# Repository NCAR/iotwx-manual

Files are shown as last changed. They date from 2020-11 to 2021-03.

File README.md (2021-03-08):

# IoTwx Manual

The process for building your station follows 5 major steps:

1. [PLAN](/plan): in this step you will plan out the design of your
   station. The components, sensors, physical design, etc. will all be
   taken into account during this phase.
2. [BUILD](./build): in this step you will begin the building process.
   You will gather your frame parts, wires, and PVC and build the frame
   so it is ready for your sensors and microcontrollers.
3. [FLASH](./flash): in this step you will build the source files and
   flash them onto your device. Should you want to flash the binaries
   directly, there are instructions to do so.
4. [DATA](./data): in this step you will set up how your data will be 
   transmitted, stored and otherwise displayed, archived or distrubuted.
4. [TEST](./test): making sure each node works as expected will insure
   the best experience for your deployment.
5. [DEPLOY](./deploy): siting and deploying are the final step in
   getting you on your way to your first 3d-printed automated weather
   station.
   
   As this is a community driven project, we value your feedback and contributions to improve the weather station. 
   To contribute updates and changes, you may fork and modify this repo for merging or, more simply, submit issues or comments via [New Issues button]( https://github.com/NCAR/iotwx-manual/issues)

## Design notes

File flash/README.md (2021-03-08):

# Flashing Microcontrollers

Each station node is build atop a microcontroller, where each
microcontroller is connected to one or more sensors either directly or
by [Grove hubs](https://www.seeedstudio.com/Grove-I2C-Hub.html). 

IotWx is designed to be used with the [m5Stack Atom Lite](https://m5stack.com/collections/m5-core/products/atom-lite-esp32-development-kit)
ESP32-Pico based microcontroller.  

There are two nodes that the core Arduino code has been developed for.
Before compiling the microcode onto the Arduino, you will also need to
install the core IoTwx shared library which controls many of the
communications and initialization functions of each node.

This core library can found at the following repository. It should be
installed in your `Arduiono/libraries` directory and once installed, you
may use it by the `#include "IoTwx.h"` directive.

* [https://github.com/NCAR/esp32-atomlite-arduino-iotwx](https://github.com/NCAR/esp32-atomlite-arduino-iotwx)

Please see the
[parts list](https://drive.google.com/file/d/1lAb784yfsxWOiH-yVCXQ3Ii0yEgUmtUQ/view?usp=sharing)
for the microcontroller, sensors and cables required or recommended to
build and connect a base system.

## Preparing Your System

You will need to install the [latest version of Arduino](https://www.arduino.cc/en/Main/Software) on your system to begin.

There are a few other steps you will need to complete:

* install the required ESP32 Pico / M5 Stack Atom lite boards; a comprehensive instruction set is [here](https://docs.m5stack.com/#/en/arduino/arduino_development)
* install the [arduino-esp32fs-plugin](https://github.com/me-no-dev/arduino-esp32fs-plugin) that will allow SPIFFS file uploads to ESP32 boards
* install the following libraries through the Arduino IDE:
  * MQTT library from 256dpi [https://github.com/256dpi/arduino-mqtt](https://github.com/256dpi/arduino-mqtt)
  * SeeedStudio VEML6070 library [https://github.com/Seeed-Studio/Seeed_VEML6070](https://github.com/Seeed-Studio/Seeed_VEML6070)
  * SeeedStudio BME280 library [https://github.com/Seeed-Studio/Grove_BME280](https://github.com/Seeed-Studio/Grove_BME280)
  * SeeedStudio BME680 library [https://github.com/Seeed-Studio/Seeed_BME680](https://github.com/Seeed-Studio/Seeed_BME680)
  * ArduinoJson library [https://github.com/bblanchon/ArduinoJson](https://github.com/bblanchon/ArduinoJson)
  * FastLED library [https://github.com/FastLED/FastLED](https://github.com/FastLED/FastLED)
  * NTPClient library [https://github.com/arduino-libraries/NTPClient](https://github.com/arduino-libraries/NTPClient)

## Editing and Flashing Configuration Files

Each node must contain a configuration file in order to operate.  The file contains information about WiFi connections, MQTT connections and some information about the node.

We are using the [ESP32 SPIFFS filesystem](https://docs.espressif.com/projects/esp-idf/en/latest/esp32/api-reference/storage/spiffs.html) to store the configuration.  In the repositories of each node, you will find a `data` folder which contains a `config.json` file.

### `config.json` details

The typical config file  follows:

```json
{    
    "iotwx_local_config":"1",
    "iotwx_id":"m5atom/esp32/aaffbbcc",
    "iotwx_mq_ip":"",
    "iotwx_mq_port":"1883",
    "iotwx_publish_interval":"1",
    "iotwx_reset_interval":"360",
    "iotwx_sensor":"grove/i2c",
    "iotwx_timezone":"21600",
    "iotwx_wifi_pwd":"",
    "iotwx_wifi_ssid":"",
    "iotwx_topic":"measurements/iotwx",
    "iotwx_max_frequency":"240"
}
```

* `iotwx_local_config` should always be set to `1`.

* `iotwx_id` should contain a _unique_ identifier for you station as a whole -- that is to say, if you have multiple nodes on the same _physical station_, they would share the same `iotwx_id`.  This identifier is also used in the data portal.

* `iotwx_mq_ip` contains the ip address (e.g. `''172.88.0.13"`) of the MQTT broker you will be using.  At the moment only one such broker is allowed. You may use the FQDN (`"mymqttsite.wx"`) but the IP address uses less power by reducing the time WiFi is on to do DNS lookups.

* `iotwx_mq_port` contains the port number of the broker, which is typically `"1883"`.

* `iotwx_publish_interval` contains the interval you wish your station to transmit in _minutes_.  Note this is relevant primarily for the Atmos node which continuously transmits at the specified interval. Hydro and Aero nodes only transmit when there is data to transmit.

* `iotwx_reset_interval` is the number of minutes between system resets.  The nodes are designed to reset every 6 hours or twice daily.  Reset is instantaneous and the system is restored to full functionality in 90 seconds after the Bluetooth acquisition phase.

* `iotwx_sensor` is the sensor string for the node and may vary based on the node.  Typically do not change this value from what is contained in the default for your node.

* `iotwx_timezone` is the GMT offset in seconds of the station timezone.

* `iotwx_wifi_pwd` and `iotwx_wifi_ssid` are the corresponding wifi password and ssid of the network your node will connect to.  Note, it is not necessary (but would be unusual) for all nodes to connect to the same WiFi network.

* `iotwx_topic` contains the MQTT topic your node will publish to.  It is not necessary for all nodes to publish to the same topic, but if you are using the CHORDS MQTT Orchestrator ([GitHub - NCAR/chords-mqtt-orchestrator](https://github.com/NCAR/chords-mqtt-orchestrator)), then you will need to adjust it accordingly to route your messages where they belong.  The current default is `"measurements/iotwx"`

* `iotwx_max_frequency` is the CPU frequency (in Mhz) you wish your node to run  on.  The m5Stack Atom Lite can be run at frequencies up to 240, but has only been tested down 40 Mhz.  The AeroNode must be set to above `"160"` and runs best at `"240"`.  The Hydro node has been successfully configured at `"40"`  and the Atmos node's best performance is at `"80"`.  Varying the value has power-saving benefits, where we have seen 20-50% reduction in power consumption of a node.

## Atmos Node

The Atmos node is comprised of two sensors and two 3d-printed housing
units. The first sensor houses the atmospheric conditions for air
temperature, humidity and barometric pressure. It can be fitted with the
[Seeedstudio BME280 Grove](https://www.seeedstudio.com/Grove-BME280-Environmental-Sensor-Temperature-Humidity-Barometer.html)
environmental sensor, or if you would like to obtain aggregate VOC
measurements, you can fit the housing with the
[BME680 Grove](https://www.seeedstudio.com/Grove-Temperature-Humidity-Pressure-and-Gas-Sensor-for-Arduino-BME680.html)
sensor. The code is designed to work with both sensors (but not
simultaneously). These parts can be found in the
[parts list](https://drive.google.com/file/d/1lAb784yfsxWOiH-yVCXQ3Ii0yEgUmtUQ/view?usp=sharing).

### Radiation Shield

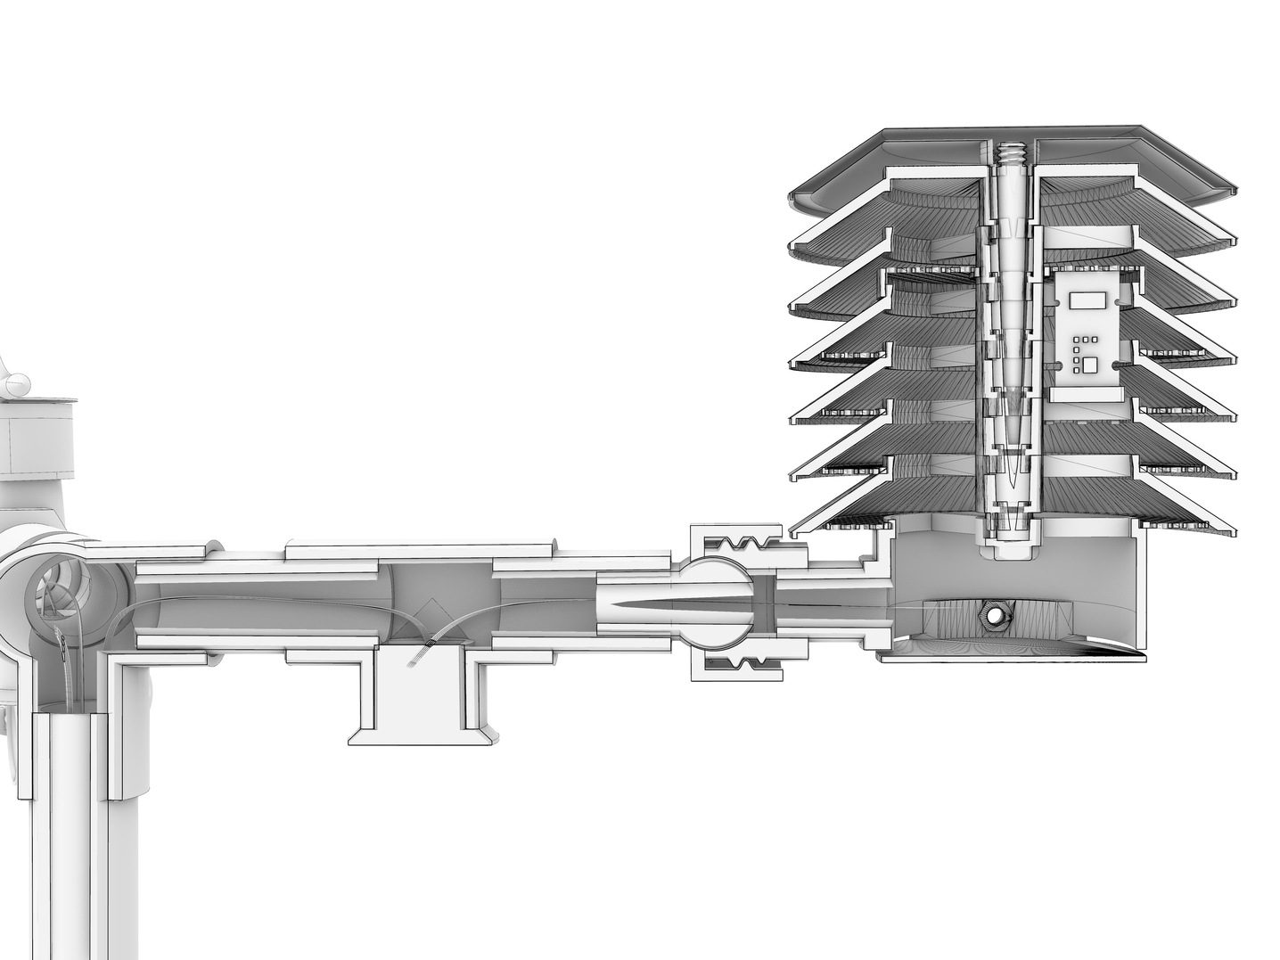
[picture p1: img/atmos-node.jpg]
atmos node


The radiation shield sensor captures the following measurements:
temperature, humidity, barometric pressure, and optionally VOC (if using
the BME680 sensor).

**PRINTING**

* the radiation shield design 3d print files can be found in the
  [`/build/stl/atmos`](https://github.com/NCAR/iotwx-manual/tree/master/build/stl/atmos) page. If you need to
  print, you will need to follow the instructions there to print the
  housing.

**FLASHING**

* the code to flash the node can be found in the
  [esp32-atomlite-arduino-atmos-node repository](https://github.com/NCAR/esp32-atomlite-arduino-atmos-node).
  You will to follow the instructions there to understand the Arduino
  flashing requirements and procedures.

### UV

Because the UV measurement is part of the Atmos node, the code already
includes the capability to capture and transmit measurements. It is
integrated in to the
[esp32-atomlite-arduino-atmos-node repository](https://github.com/NCAR/esp32-atomlite-arduino-atmos-node)
and hence no other changes or files are necessary to flash once that
file has been uploaded to the microcontroller.

## Hydro Node

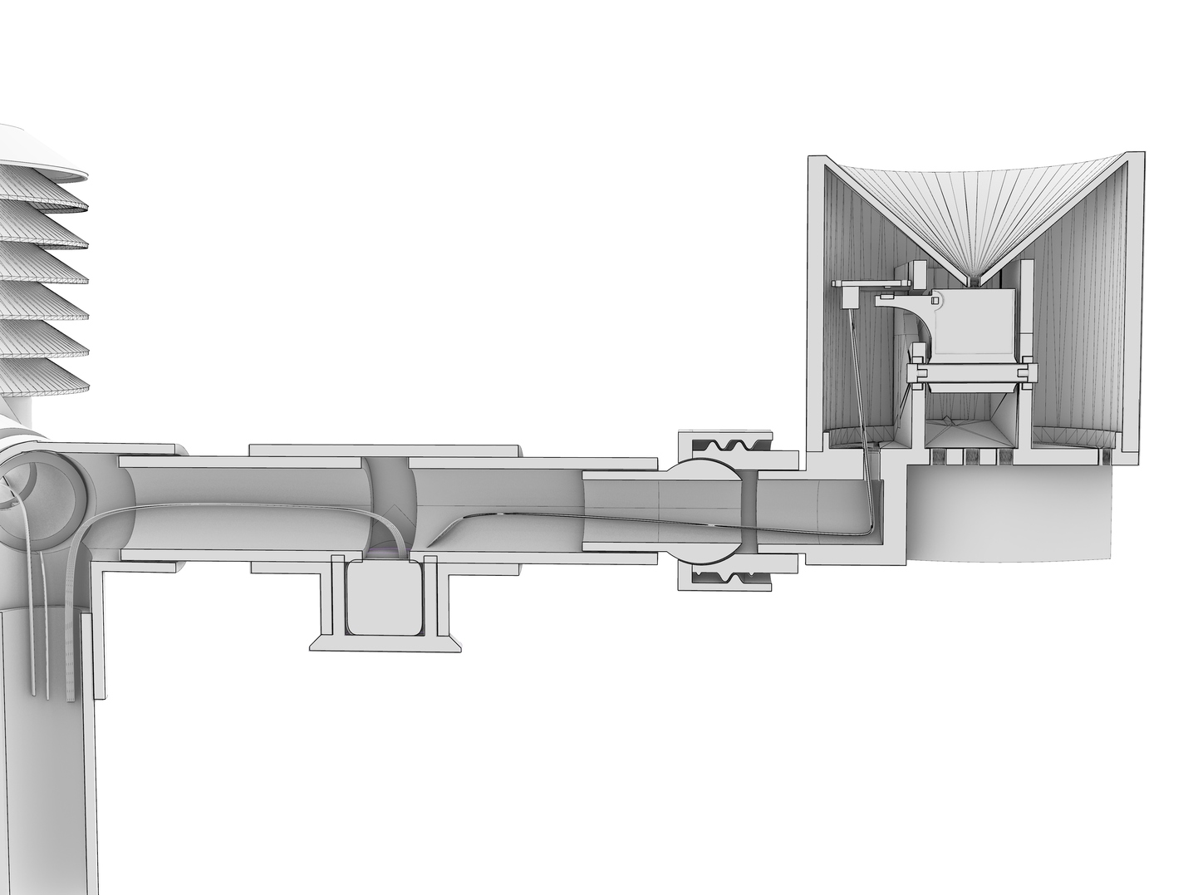
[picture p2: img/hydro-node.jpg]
hydro node


The hydro node is designed to collected and transmit precipitation
measurements.  

**PRINTING** 

* the rain gauge design 3d print files can be found in the
  [`/build/stl/hydro`](https://github.com/NCAR/iotwx-manual/tree/master/build/stl/hydro)
  page. If you need to print, you will need to follow the instructions
  there to print the housing.

**FLASHING**

* the code to flash the node can be found in the
  [esp32-atomlite-arduino-hydro-node repository](https://github.com/NCAR/esp32-atomlite-arduino-hydro-node).
  You will to follow the instructions there to understand the Arduino
  flashing requirements and procedures.

## Aero Node

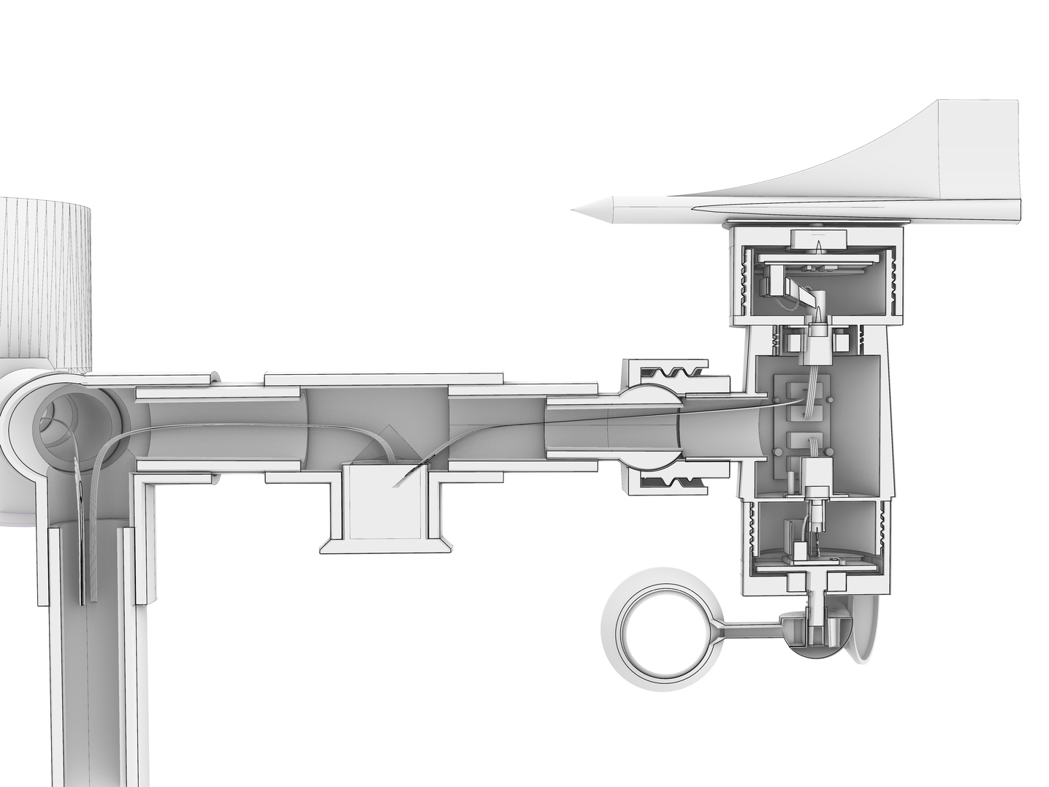
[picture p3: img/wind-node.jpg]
aero node


The aero node is designed to collect wind vane & anemometer wind speed
and direction.

* Instructions for printing and flashing are forthcoming.

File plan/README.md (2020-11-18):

# Planning Your Station Build & Deployment

In general, planning your station is easy. While we recommend you use PVC for the 
main frame of the station, you may use any materials you like as long as they bind to 
the ABS/PLA plastic of the 3D-printed parts.

The base configuration of the station includes three nodes and the power (we'll 
consider the power a node as well moving forward).  You may reduce or expand those 
nodes based on your specific needs, but the base configuration will be assumed in 
this guide.

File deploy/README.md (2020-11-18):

## Picking a good site

   ### Classroom Site Near Wifi
   ### Site Away From Wifi Using USB Modem

## Publishing and Visualizing Station Data

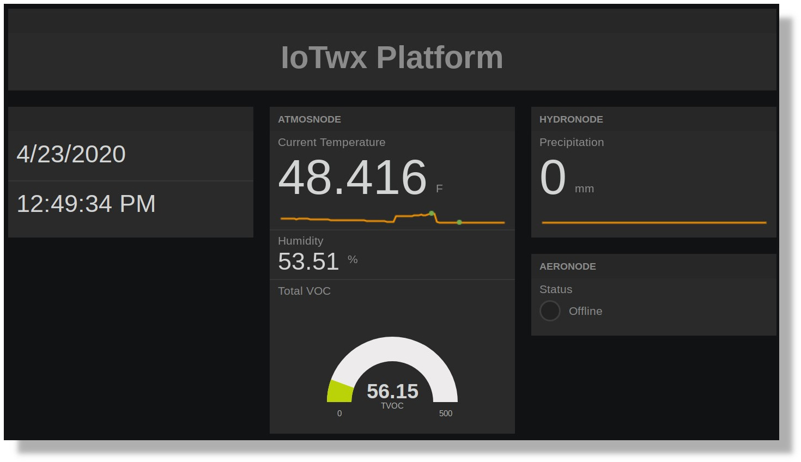
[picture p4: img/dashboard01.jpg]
dashboard


--

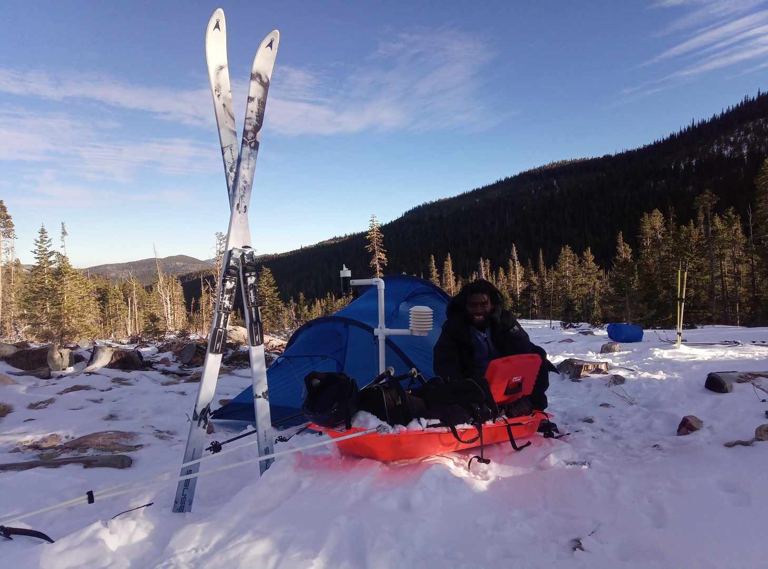
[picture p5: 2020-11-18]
img/deployment1.jpg

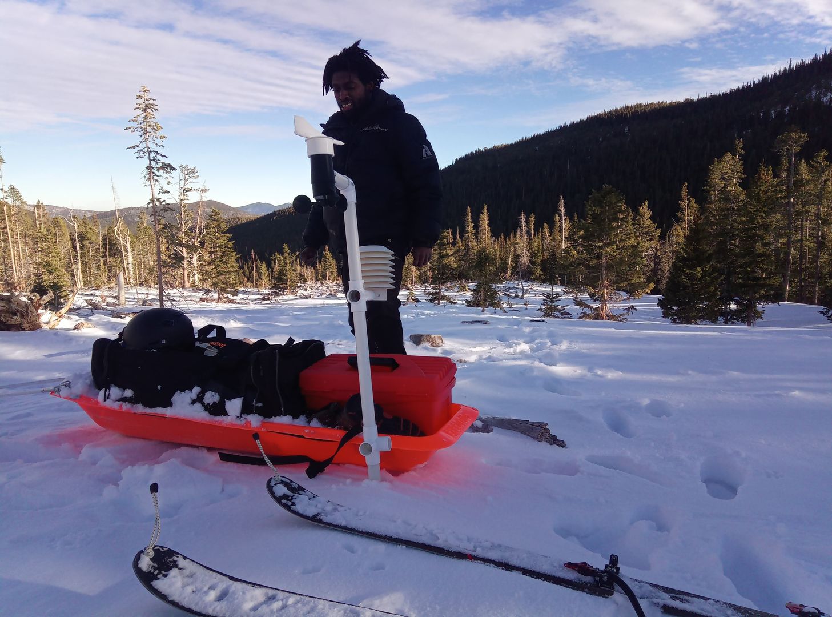
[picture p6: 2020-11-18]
img/mission.jpg

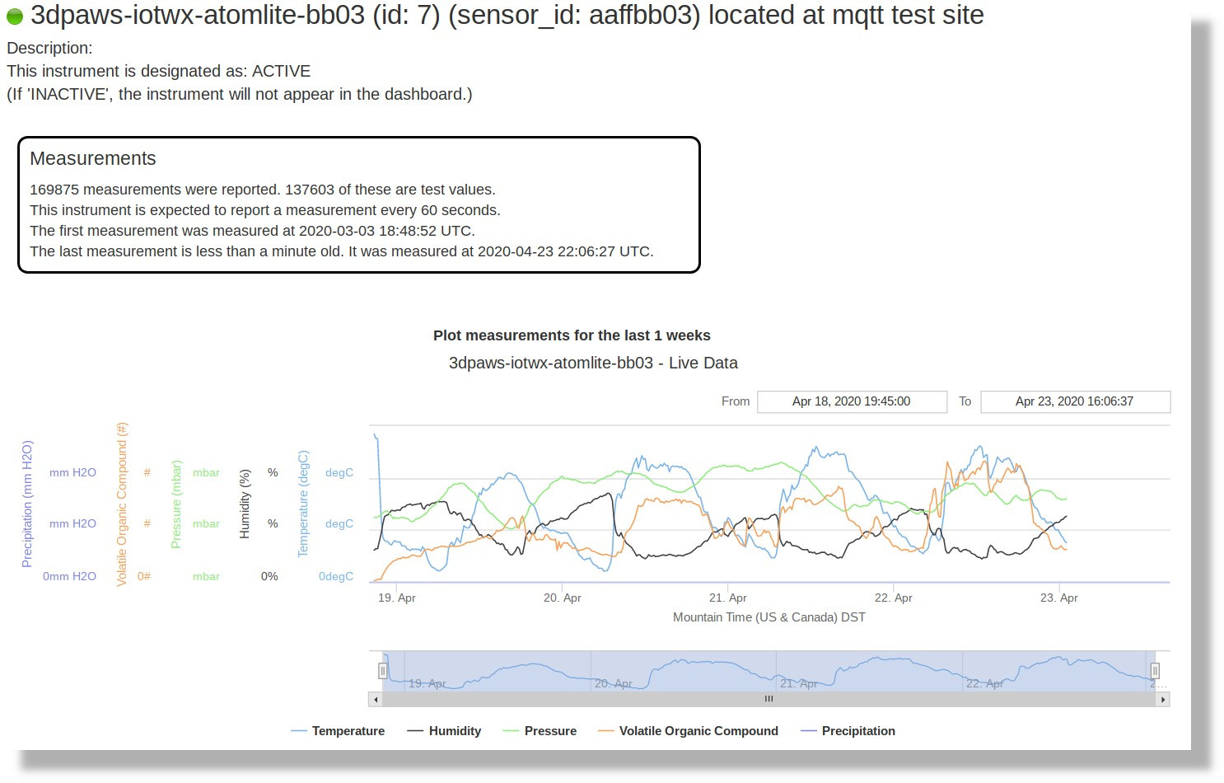
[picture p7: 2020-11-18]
img/chords01.jpg

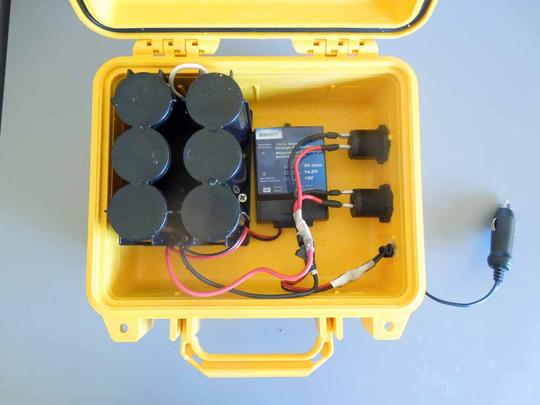
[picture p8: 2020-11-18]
img/powercomm-node.jpg

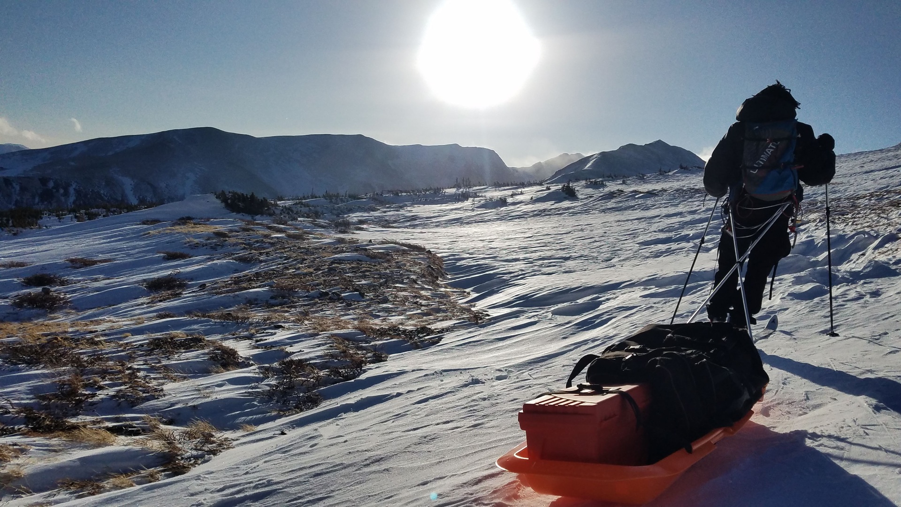
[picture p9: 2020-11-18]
img/deployment2.jpg

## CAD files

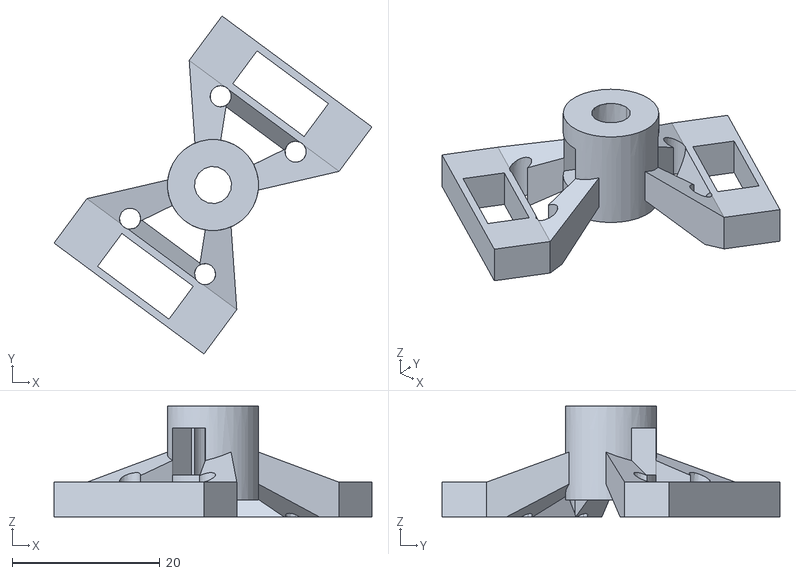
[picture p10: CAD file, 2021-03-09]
build/stl/aero/aero_wnvn_coupler_4.stl
43.1 x 45.8 x 15.0

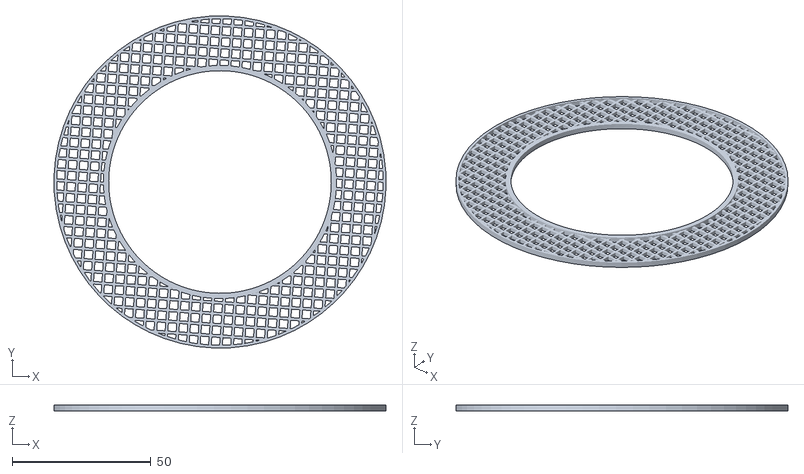
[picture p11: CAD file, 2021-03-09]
build/stl/atmos/rs_screen_ring.stl
119.9 x 119.9 x 2.00

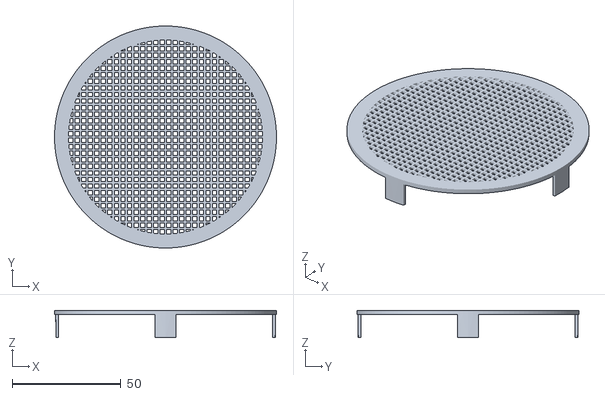
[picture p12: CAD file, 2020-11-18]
build/stl/hydro/hyd_funnel_screen.stl
101.9 x 101.9 x 12.5

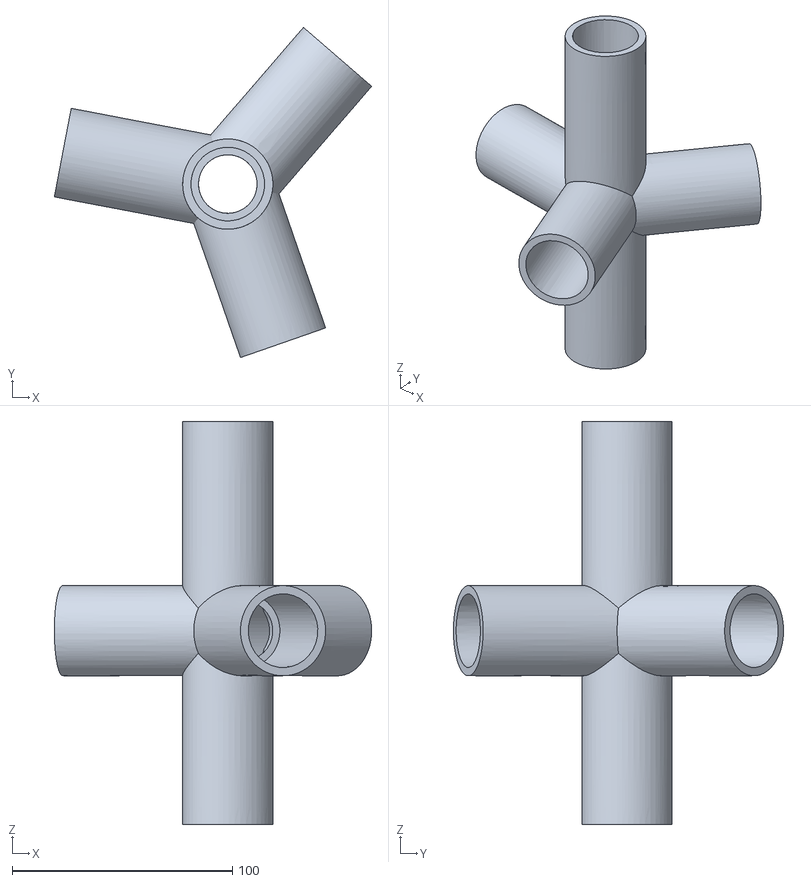
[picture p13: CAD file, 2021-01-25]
build/stl/pvc/pvc_mid_splitter.stl
144.2 x 150.0 x 183.1

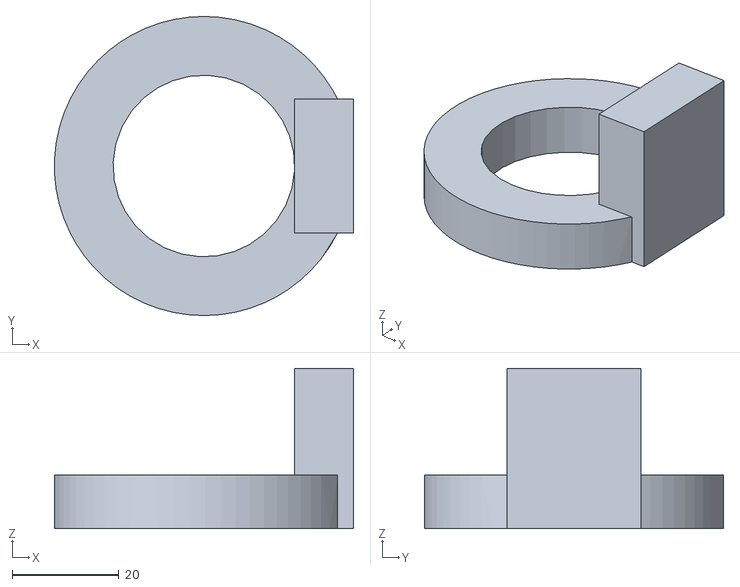
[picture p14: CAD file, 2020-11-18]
build/stl/solar/sol_11mil_clamp.stl
56.0 x 56.0 x 30.0

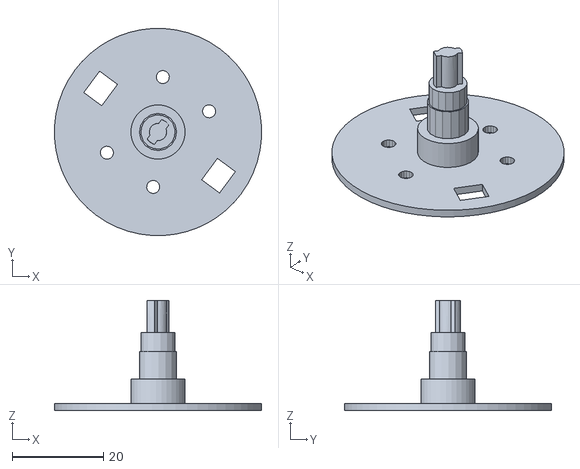
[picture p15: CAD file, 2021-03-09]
build/stl/aero/aero_wnvn_plate_4.stl
45.5 x 45.5 x 24.2

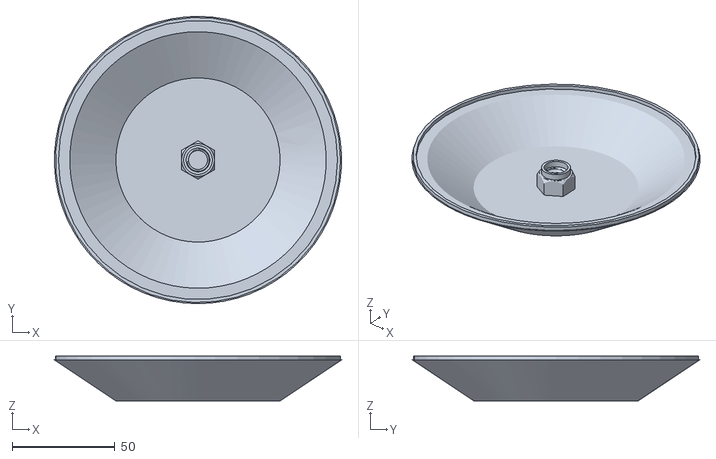
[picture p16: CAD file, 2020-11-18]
build/stl/atmos/rs_top_leaf.stl
139.8 x 139.9 x 21.9

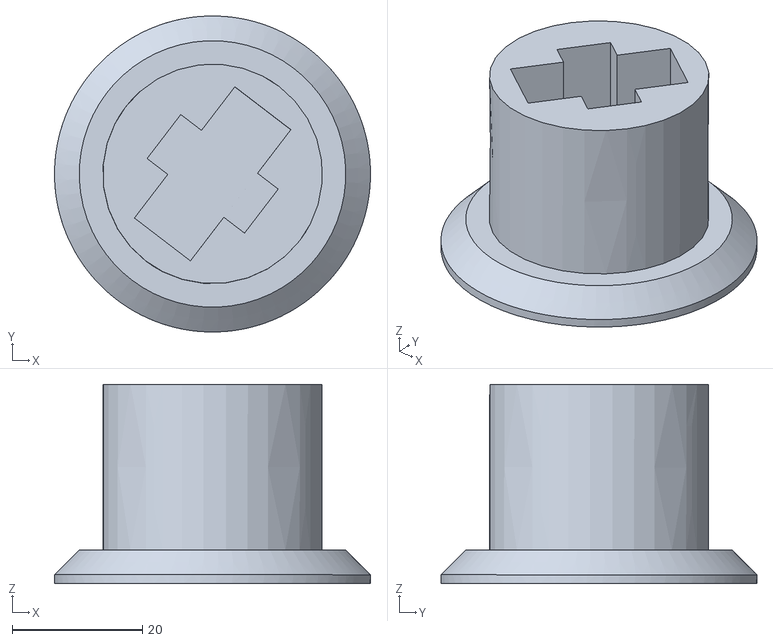
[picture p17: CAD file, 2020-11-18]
build/stl/hydro/pvc_micro_holder.stl
48.5 x 48.5 x 30.6

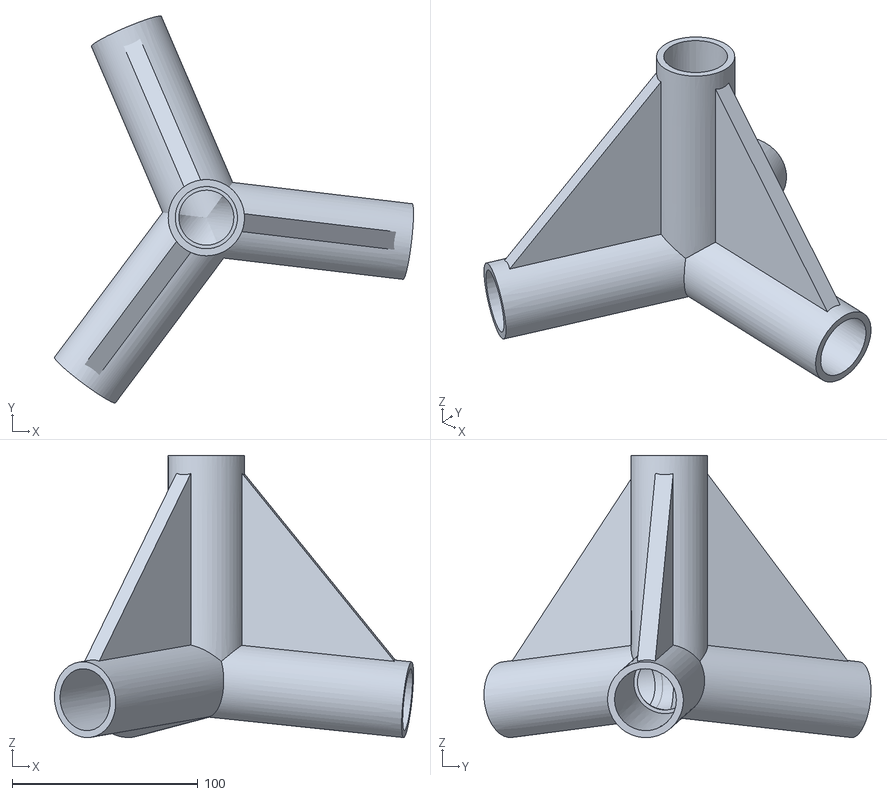
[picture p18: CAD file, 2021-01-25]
build/stl/pvc/pvc_tripod_base_2.stl
193.1 x 208.1 x 151.8

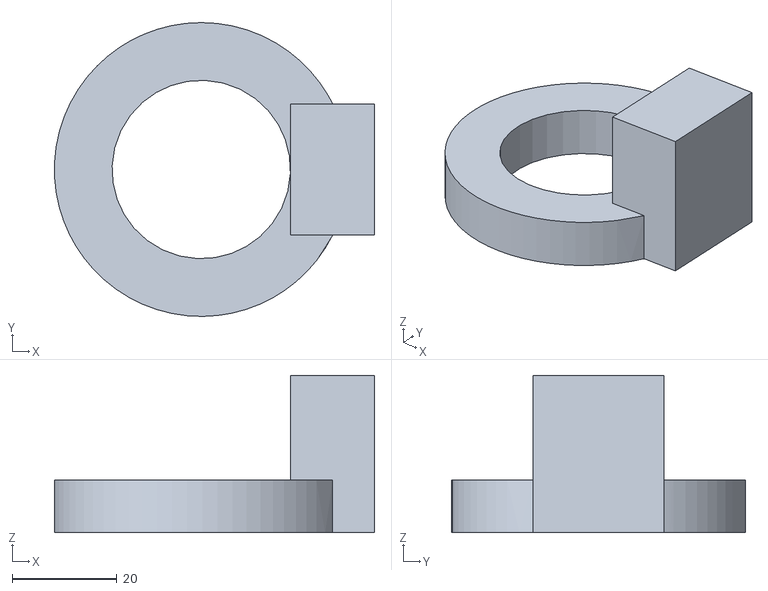
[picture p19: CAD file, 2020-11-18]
build/stl/solar/sol_16mil_clamp.stl
61.0 x 56.0 x 30.0

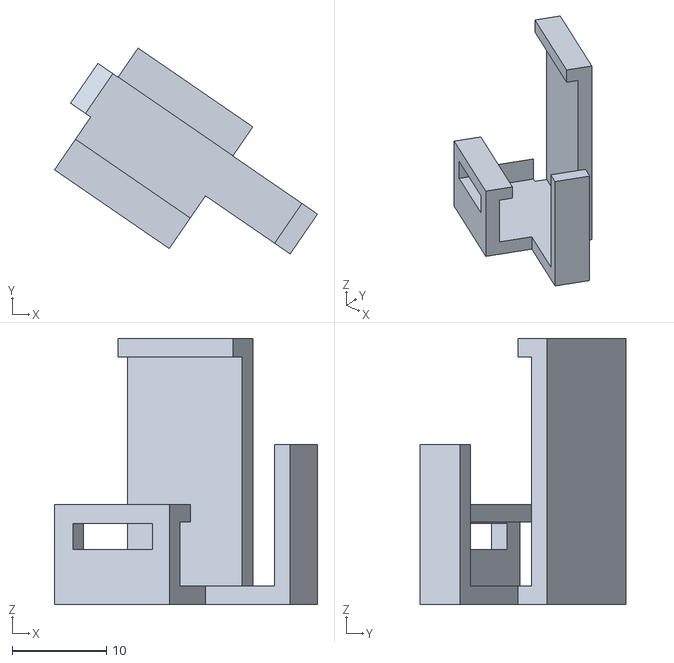
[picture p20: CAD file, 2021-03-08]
build/stl/aero/aero_micro_harness.stl
27.9 x 21.8 x 28.2

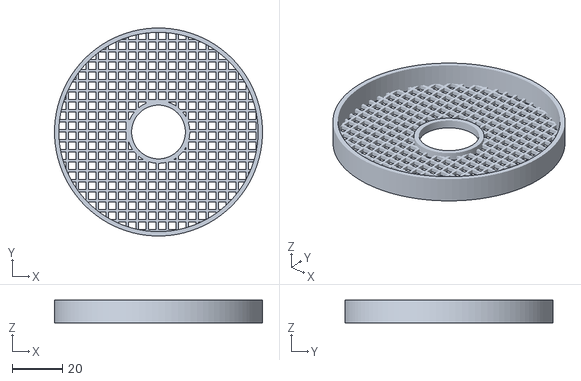
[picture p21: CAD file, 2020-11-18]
build/stl/atmos/rs_center_screen.stl
83.0 x 83.0 x 9.00

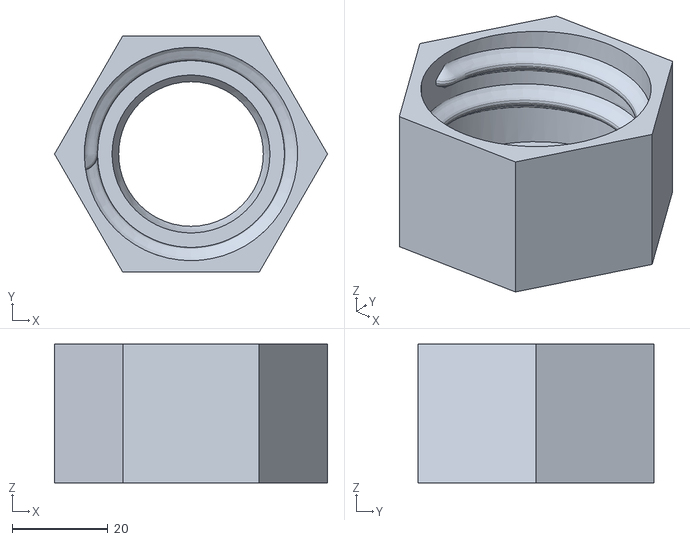
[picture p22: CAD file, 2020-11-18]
build/stl/hydro/swvl_outerlock.stl
56.9 x 49.3 x 29.0

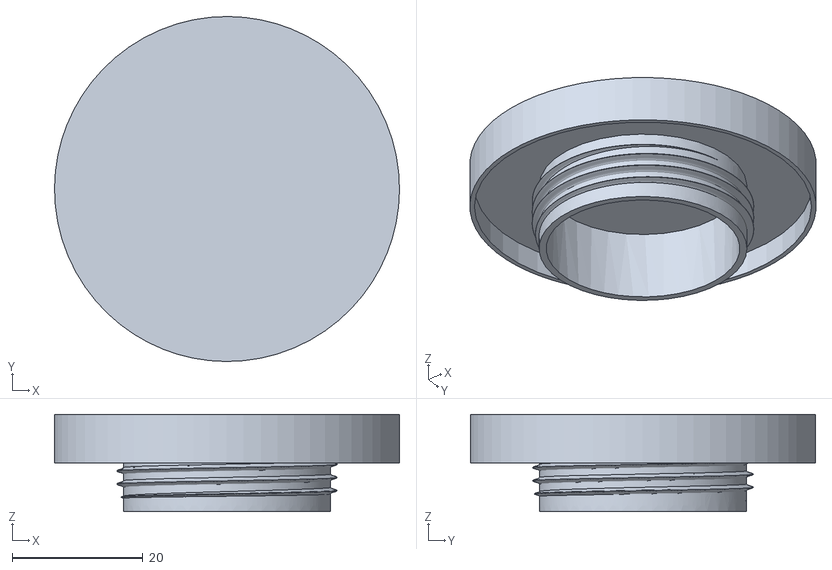
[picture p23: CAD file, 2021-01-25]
build/stl/aero/aero_wnvn_cap_2.stl
52.8 x 52.8 x 14.9

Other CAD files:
build/stl/pvc/pvc_tri_splitter_2.stl
build/stl/atmos/uv_cap.stl
build/stl/hydro/hyd_funnel.stl
build/stl/pvc/pvc_tripod_base_3.stl
build/stl/aero/aero_wnvn_clips_3.stl
build/stl/aero/aero_wnvn_coupler_3.stl
build/stl/aero/aero_wnvn_plate_3.stl
build/stl/atmos/rs_base.stl
build/stl/atmos/rs_base_plate.stl
build/stl/atmos/rs_clip.stl
build/stl/atmos/rs_fasteners.stl
build/stl/atmos/rs_shaft.stl
build/stl/atmos/rs_single_leaf.stl
build/stl/atmos/swvl_balljoint_bar.stl
build/stl/atmos/swvl_innerlock.stl
build/stl/atmos/uv_tube.stl
build/stl/hydro/hyd_fulcrum.stl
build/stl/hydro/hyd_rain_guage.stl
build/stl/hydro/swvl_balljoint_bar.stl
build/stl/hydro/swvl_innerlock.stl
build/stl/pvc/pvc_balljoint_bar.stl
build/stl/pvc/pvc_en_cap.stl
build/stl/pvc/pvc_en_tube.stl
build/stl/pvc/pvc_innerlock.stl
build/stl/pvc/pvc_stake.stl
build/stl/pvc/pvc_tjoint.stl
build/stl/pvc/pvc_tri_splitter.stl
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

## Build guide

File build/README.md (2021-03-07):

# Building Your Station

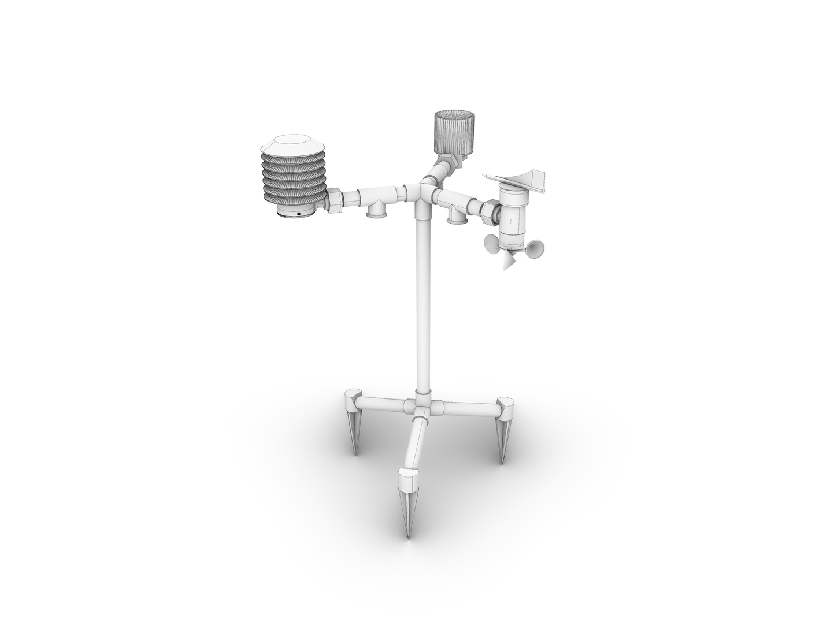
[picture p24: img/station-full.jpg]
atmos node


**PARTS LIST**

Before getting started, you should consult the complete list of parts
and hardware that can be found at:

* See the
  [Google spreadsheet](https://drive.google.com/file/d/1lAb784yfsxWOiH-yVCXQ3Ii0yEgUmtUQ/view?usp=sharing)
  for the full, up-to-date list of _non-printed_ parts for building a
  complete station. The vast majority of parts can be found on Amazon,
  through online electronics distributors and through your local
  hardware store.

**Note:** the base case build has quantities preset to 1 item. Also,
**alternative power options** are also listed in this document for users
interested in further customizing their station to specific power needs.

If you only wish to do tabletop testing, you will only need to follow
the [flash instructions](https://github.com/NCAR/iotwx-manual/tree/master/flash) for the microcontroller and then proceed to
the [tabletop testing](#skeletontabletop-testing). This will eliminate
the need for making wiring bundles, constructing a PVC frame or printing
the 3d-printed housing.

## 3D-Printing

All parts can be found in the [stl](./stl) folder and in conjection 
with the station assembly instructions.

Reference stations have been produced with PLA+ material, but
ABS and other materials may be used, provided you have 
enough expertise using them.

## Framing

* [PVC Framing Stand Assembly](./NCAR_PVC_Node_Assembly_Doc.pdf) instruction set

## Wiring

All wiring is based on the Grove / PH2.0-4P which is a 4 pin cable capable of carrying digital, analog and I2C signals.  Grove cables come in buckled and unbuckled styles as well as many sizes from 20cm to 2m.  Grove cables can also be connected directly to GPIOs with both male and female jumper cables.

An assortment of cables can be reliably found here: [Search results for: grove cable – Mouser](https://www.mouser.com/Search/Refine?Keyword=grove+cable).

Long cable (1m - 2m) can be found here: [Unbuckled Grove Cable 1m/2m/50cm/20cm/10cm | m5stack-store](https://m5stack-store.myshopify.com/collections/m5-accessory/products/4pin-buckled-grove-cable)

### Qwicc

There are many Grove sensors provided by SeeedStudio, but another connector standard also exists to open up even more sensors. Deveopled by Sparkfun, [Qwicc](https://www.sparkfun.com/qwiic) is also a 4 pin I2C connector that is capable of being connected to Grove and visa-versa.  If you wish to explore the wide variety of sensors, browse what's possible from [Qwiic Sensors: SparkFun Electronics](https://www.sparkfun.com/categories/399)), [STEMMA/Qwiic Sensors: Adafruit Industries, Unique &amp; fun DIY electronics and kits](https://www.adafruit.com/category/1005), [Qwiic ModulesL Smart Prototyping Zio](https://www.smart-prototyping.com/Zio/zio-modules) and others. 

We have been successful using Adafruit Qwiic digital compass sensors in the AeroNode.

### GPIO Connections

If you want to connect directly to the GPIO (either using the recommended reference microcontroller m5Stack Atom Lite or some other microcontroller), the male and female jumper cables can be used as needed:

* male 4 pin Grove Jumper cable: [110990210 Seeed Studio | Mouser](https://www.mouser.com/ProductDetail/Seeed-Studio/110990210?qs=1%252B9yuXKSi8A2O44lPDM%252BLw%3D%3D)

* female 4 pin Grove Jumper cable: [110990028 Seeed Studio | Mouser](https://www.mouser.com/ProductDetail/Seeed-Studio/110990028?qs=1%252B9yuXKSi8Bgmubyjm2m%2Fw%3D%3D)

## Station Assembly

You can find the various assembly instructions in the provided PDF files:

* [Aero Node Assembly](./NCAR_AERO_Node_Assembly_Doc.pdf) instruction set
* [Hydro Node Assembly](./NCAR_HYDRO_Node_Assembly_Doc.pdf) instruction set
* [Atmos Node Assembly](./NCAR_ATMOS_Node_Assembly_Doc.pdf) instruction set

This is a community driven project, if you would like to contribute proposed changes to the assembly instructions or see other issues please submit it via [New Issues]( https://github.com/NCAR/iotwx-manual/issues)

## Skeleton/Tabletop Testing

The IoTwx system is designed to allow for rapid and flexible testing well _before_ assembly.  In fact, you can set up a system without any frame at all to burn in, test or add new components.

Simply flash the code onto the microcontroller, connect the sensors and you're done.

## Solar Assembly

*coming soon

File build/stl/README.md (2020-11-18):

# STL files for printing

There are directories containing all the STL files necessary to print the 
station.  The following nodes are available for printing.  Please consult
the [parts list](https://drive.google.com/file/d/1lAb784yfsxWOiH-yVCXQ3Ii0yEgUmtUQ/view?usp=sharing) and [flash instructions](https://github.com/NCAR/iotwx-manual/tree/master/flash) for the other parts (electronics, etc.) 
and code that are necessary to construct a fully operational node.

* [atmos node files](./atmos) are available for the radiation shield
* [hydro node files](./hydro) are available for the tipping bucket
* [aero node files](./aero) are available for the wind vane and anemometer 
* [solar assembly files](./solar) are available for the solar panel assembly
* [pvc connectors files](./pvc) are available for the pvc connectors

# Acknowledgements

This design would not have been possible without the enumerable contributions of others.

In particular, the Atmos node is inspired by the work of the [3D-PAWS radiation shield assembly](https://sites.google.com/ucar.edu/3dpaws/instruments/radiation-shield) ((c) UCAR/COMET)
from which modifications were made to accommodate different sensor orientations, to allow
for easier insertion of the leaf screens and changes were made to the shaft for 
improved threading and durability. The Hydro node is remixed and modified from the 
original work of [RobWLake's LTB Weather Station](https://www.thingiverse.com/thing:2849562) 
(CC-BY-NC 4.0) -- changes were made to the sensor holder to accommodate a [Grove hall effect sensor](https://wiki.seeedstudio.com/Grove-Hall_Sensor/) and a debris screen, 
as well as sizing modifications so that it is easier to construct.

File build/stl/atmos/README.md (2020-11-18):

# Print Settings

Unless otherwise noted, **infill default is 50%**.

| Description | File | Quantity | Notes |
|---|---|---|---|
| Base | [rs_base.stl](./rs_base.stl) | 1 | |
| Center Screen | [rs_center_screen.stl](./rs_center_screen.stl) | 1 | |
| Sensor clip holder | [rs_clip.stl](./rs_clip.stl) | 1 | Print more than 1 if you have multiples or need extras. |
| Middle leaf | [rs_mid_leaf.stl](./rs_mid_leaf.stl) | 1 | |
| Screen Ring | [rs_screen_ring.stl](./rs_screen_ring.stl) | 4 | |
| Center shaft | [rs_shaft.stl](./rs_shaft.stl) | 1 | Print at 100% infill |
| Single leaf | [rs_single_leaf.stl](./rs_single_leaf.stl) | 1 | |
| Top leaf | [rs_top_leaf.stl](./rs_top_leaf.stl) | 1 | |
| Base Fasteners | [rs_fasteners.stl](./rs_fasteners.stl) | 2 | Print at 100% infill; print extras as needed. |  | |
| Swivel ball joint connector | [swvl_balljoint_bar.stl](./swvl_balljoint_bar.stl) | 1 | |
| Swivel ball joint inner locl |[swvl_innerlock.stl](./swvl_innerlock.stl) | 1 | |
| Swivel ball joint outer lock | [swvl_outerlock.stl](./swvl_outerlock.stl) | 1 | |
| Microcontroller holder  | [pvc_micro_holder.stl](./pvc_micro_holder.stl) | 1 | |

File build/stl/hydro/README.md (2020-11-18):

# Print Settings

Unless otherwise noted, **infill default is 50%**.

| Description | File | Quantity | Notes |
|---|---|---|---|
| Fulcrum | [hyd_fulcrum.stl](./hyd_fulcrum.stl) | 1 | Print more than 1 if you need extras |
| Funnel Screen | [hyd_funnel_screen.stl](./hyd_funnel_screen.stl) | 1 | |
| Funnel | [hyd_funnel.stl](./hyd_funnel.stl) | 1 |  |
| Rain gauge | [hyd_rain_guage.stl](./hyd_rain_guage.stl) | 1 | |
| Sensor Slot | [hyd_sensor_slot.stl](./hyd_sensor_slot.stl) | 1 |  |
| Swivel ball joint connector | [swvl_balljoint_bar.stl](./swvl_balljoint_bar.stl) | 1 | |
| Swivel ball joint inner locl |[swvl_innerlock.stl](./swvl_innerlock.stl) | 1 | |
| Swivel ball joint outer lock | [swvl_outerlock.stl](./swvl_outerlock.stl) | 1 | |
| Microcontroller holder  | [pvc_micro_holder.stl](./pvc_micro_holder.stl) | 1 | |

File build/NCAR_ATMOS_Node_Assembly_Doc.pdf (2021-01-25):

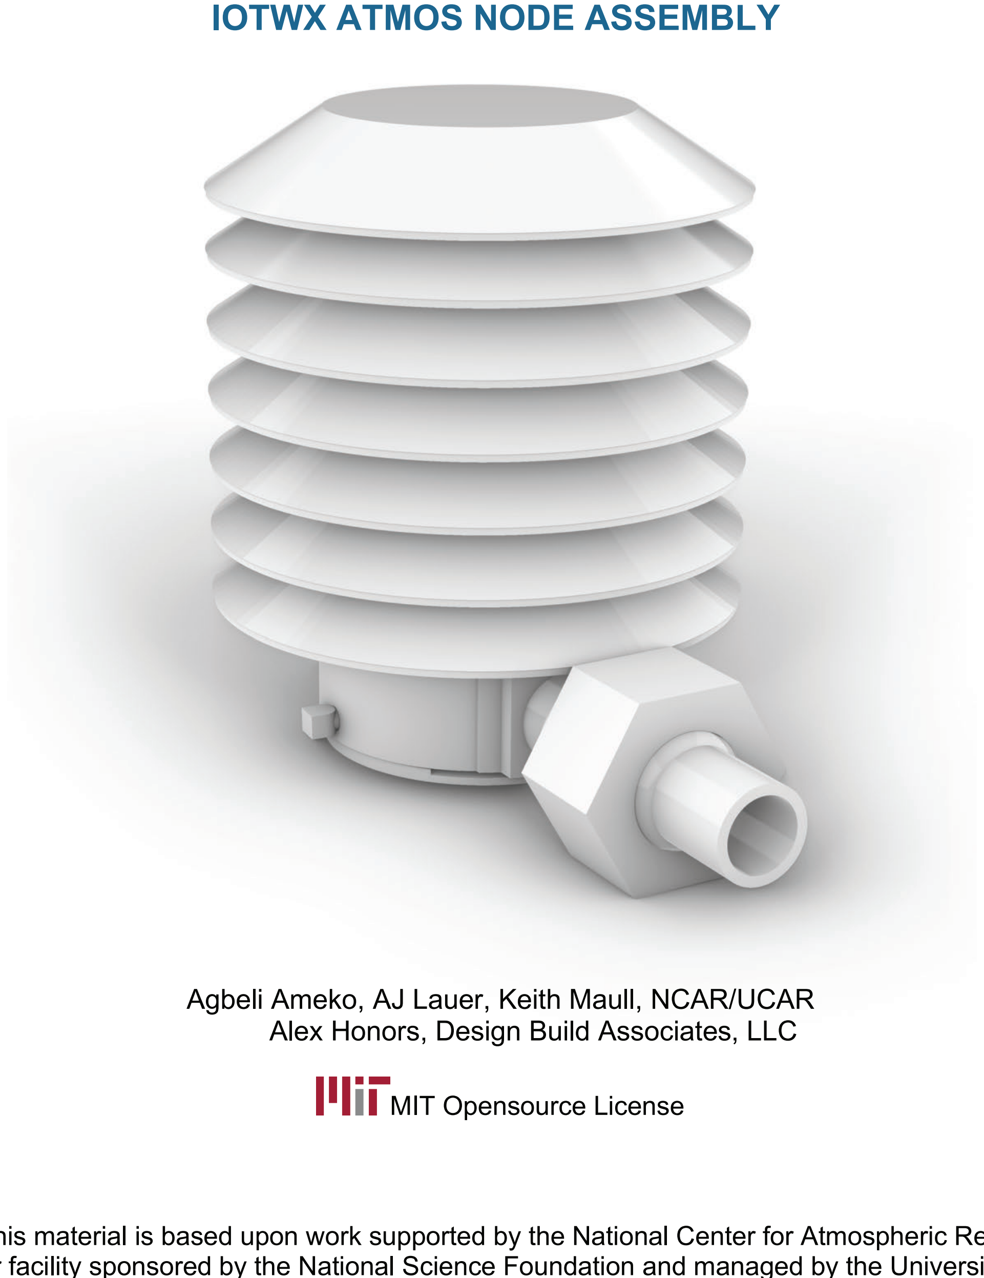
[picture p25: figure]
I O T W X AT MO S N O D E ASSEMBLY; M I T O p ensource L icense

A g beli A mek o, A J L auer, K eit h M aull, N C A R / U C A R A lex H onors, D esig n B uild A ssociat es, L L C

This mat erial is based up on work sup p ort ed by t he N at ional C ent er f or A t mosp heric R esearch, a maj or f acilit y sp onsored by t he N at ional S cience F oundat ion and manag ed by t he U niv ersit y
C orp orat ion f or A t mosp heric R esearch. A ny op inions, f inding s and conclusions or recommendat ions exp ressed in t his mat erial do not necessarily ref lect t he v iews of t he N at ional S cience F oundat ion.

This work is based on sup p ort p rov ided by t he E S I P L ab wit h sup p ort f rom t he N at ional
A eronaut ics and S p ace A dminist rat ion ( N A S A ) , N at ional O ceanic and A t mosp heric A dminist rat ion ( N O A A ) and t he U nit ed S t at es G eolog ic S urv ey ( U S G S ).

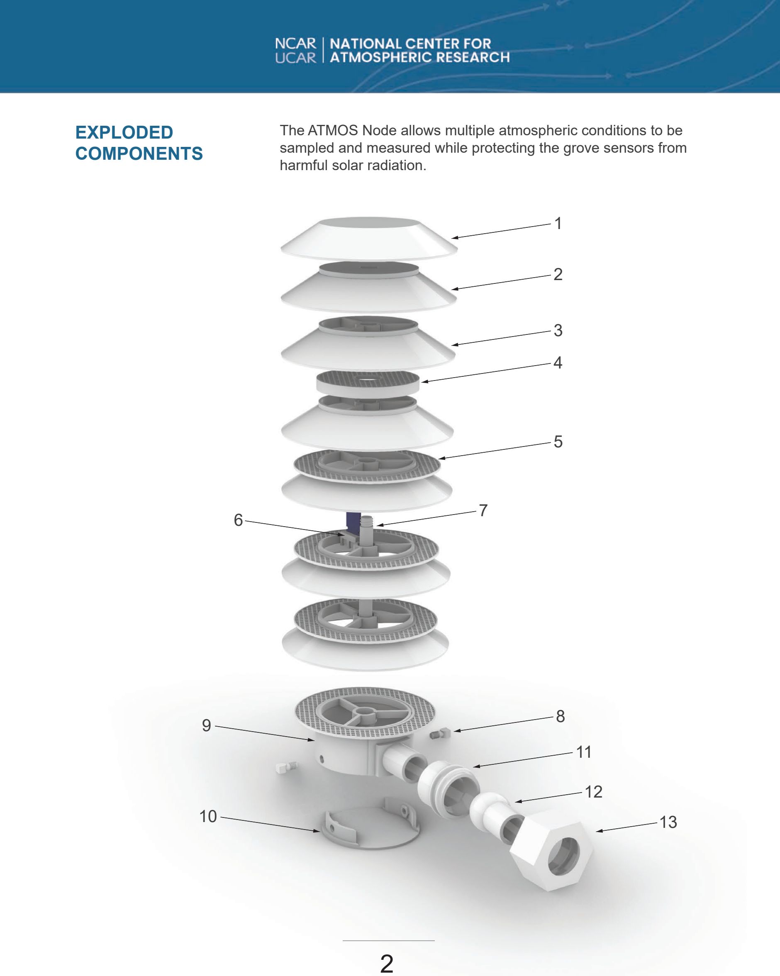
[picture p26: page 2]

EX P LO D ED
C O MP O N EN T S

The A TM O S N ode allows mult ip le at mosp heric condit ions t o be samp led and measured while p rot ect ing t he g rov e sensors f rom harmf ul solar radiat ion.

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
C O MP O N EN T S
LI ST

ASSEMBLY

N o . | C o m p o n e n t N a m e | Q u a l i t y
1 | Top L eaf | 1
2 | S ing le L eaf | 1
3 | M id L eaf | 5
4 | C ent er S creen | 1
5 | S creen R ing | 4
6 | S ensor C lip | 1
7 | S haf t | 1
8 | F ast ener | 2
9 | B ase | 1
10 | B ase P lat e | 1
11 | S wiv el I nnerlock | 1
12 | S wiv el B all J oint B ar | 1
13 | S wiv el O ut erlock | 1

A t t ach B ase P lat e t o B ase wit h 2 F ast eners. M ak e sure B ase P lat e t hreads are lined up wit h B ase holes.

# ST EP 1

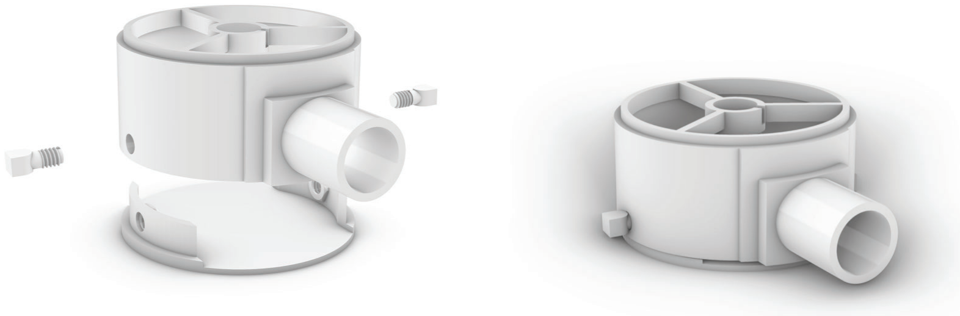
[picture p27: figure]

# ST EP 2

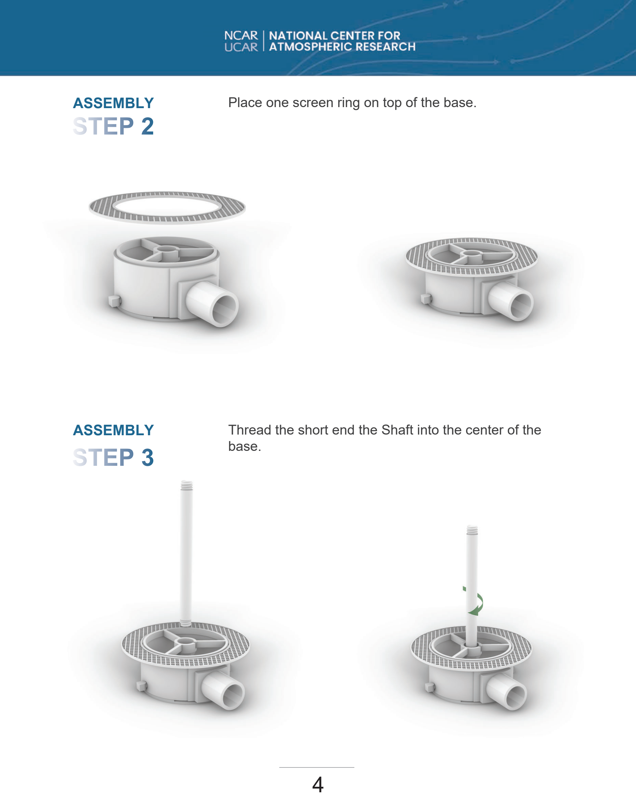
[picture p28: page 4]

ASSEMBLY | Thread t he short end t he S haf t int o t he cent er of t he
base. ST EP 3
ASSEMBLY | P lace one screen ring on t op of t he base.

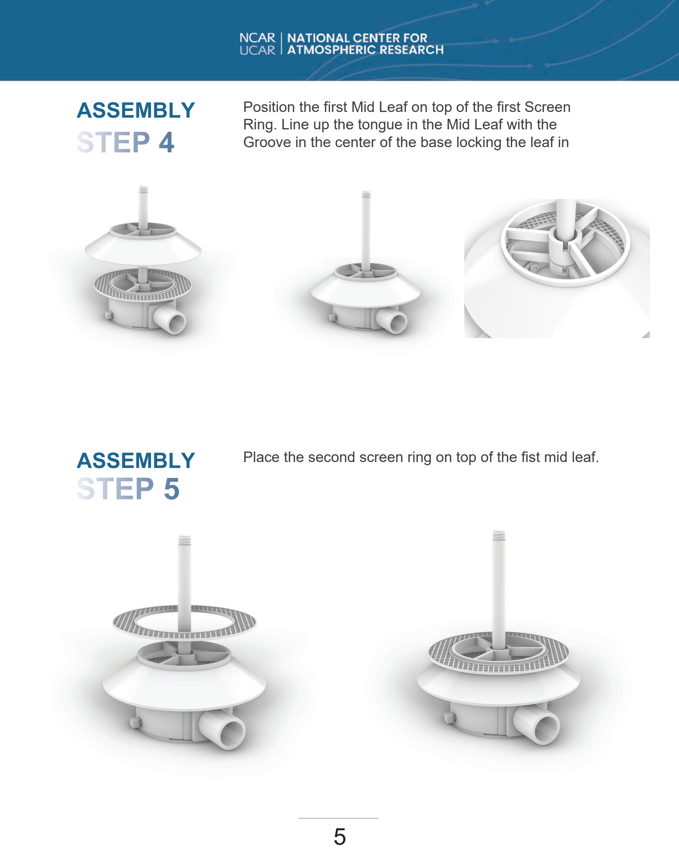
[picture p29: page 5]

ASSEMBLY P lace t he second screen ring on t op of t he f ist mid leaf .

# ST EP 5

ASSEMBLY | P osit ion t he f irst M id L eaf on t op of t he f irst S creen
| R ing . L ine up t he t ong ue in t he M id L eaf wit h t he
ST EP 4 | G roov e in t he cent er of t he base lock ing t he leaf in

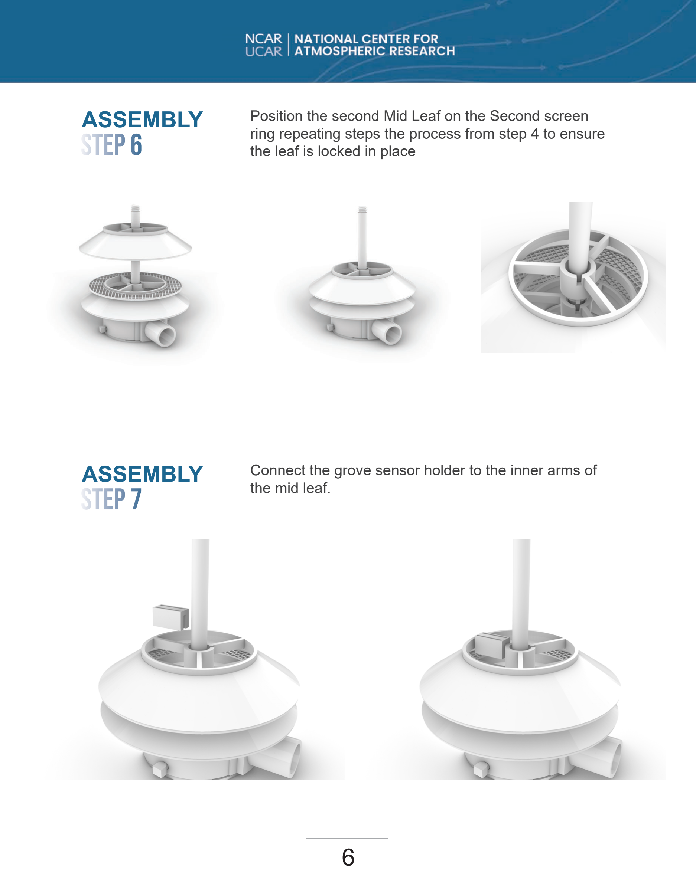
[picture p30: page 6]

ASSEMBLY C onnect t he g rov e sensor holder t o t he inner arms of t he mid leaf . STEP 7

ASSEMBLY | P osit ion t he second M id L eaf on t he S econd screen
ring rep eat ing st ep s t he p rocess f rom st ep 4 t o ensure STEP 6 | t he leaf is lock ed in p lace

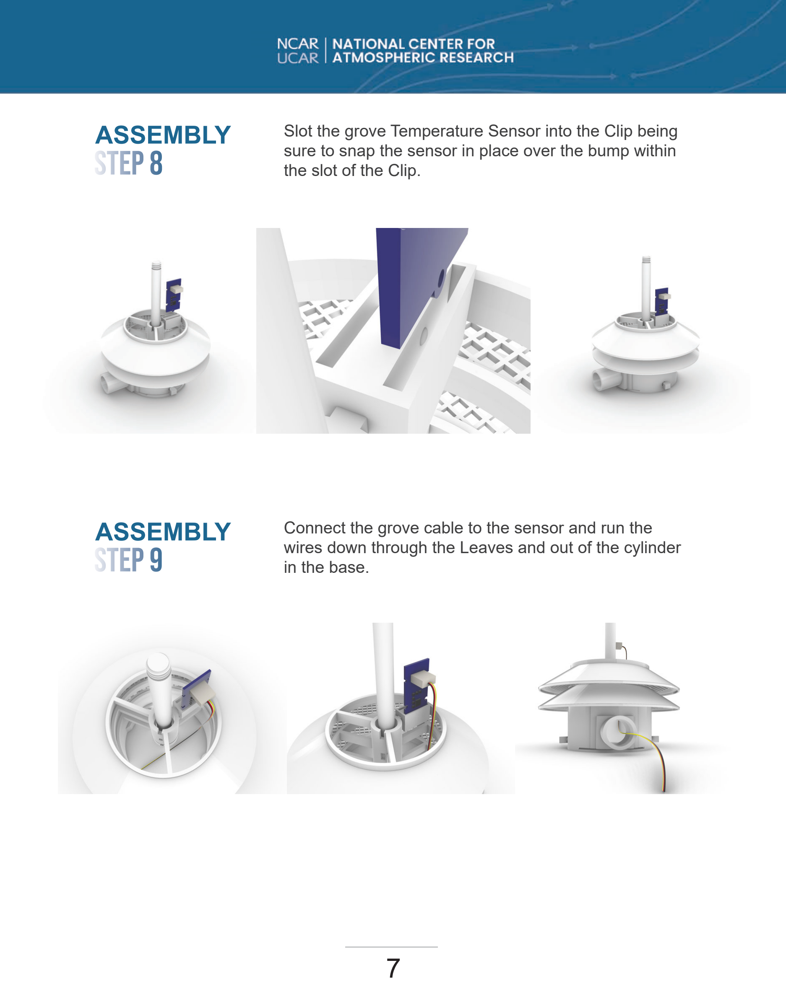
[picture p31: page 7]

ASSEMBLY | C onnect t he g rov e cable t o t he sensor and run t he
wires down t hroug h t he L eav es and out of t he cylinder STEP 9 | in t he base.
ASSEMBLY | S lot t he g rov e Temp erat ure S ensor int o t he C lip being
sure t o snap t he sensor in p lace ov er t he bump wit hin STEP 8 | t he slot of t he C lip .

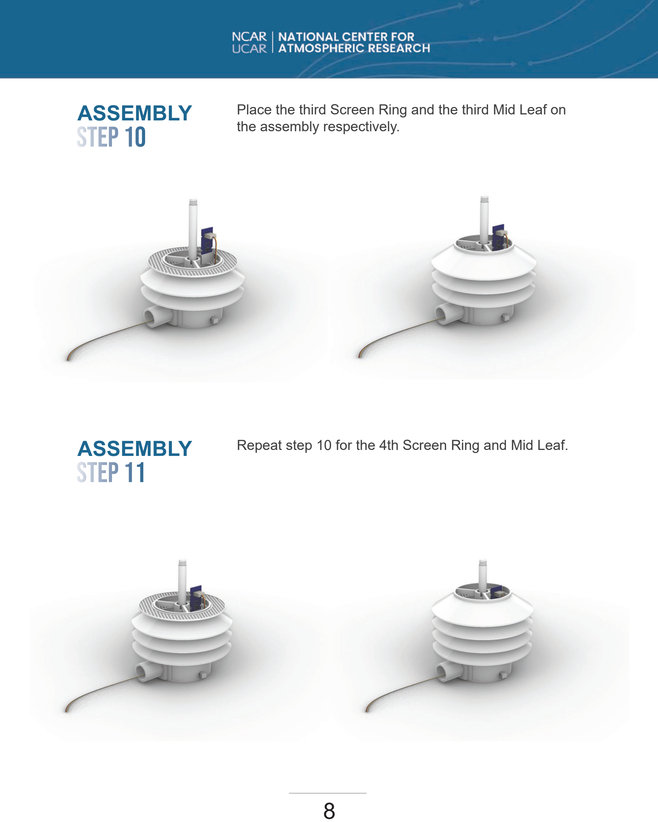
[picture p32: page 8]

ASSEMBLY R ep eat st ep 10 f or t he 4 t h S creen R ing and M id L eaf .

## STEP 11

ASSEMBLY P lace t he t hird S creen R ing and t he t hird M id L eaf on t he assembly resp ect iv ely. STEP 10

## L eaf . STEP 12

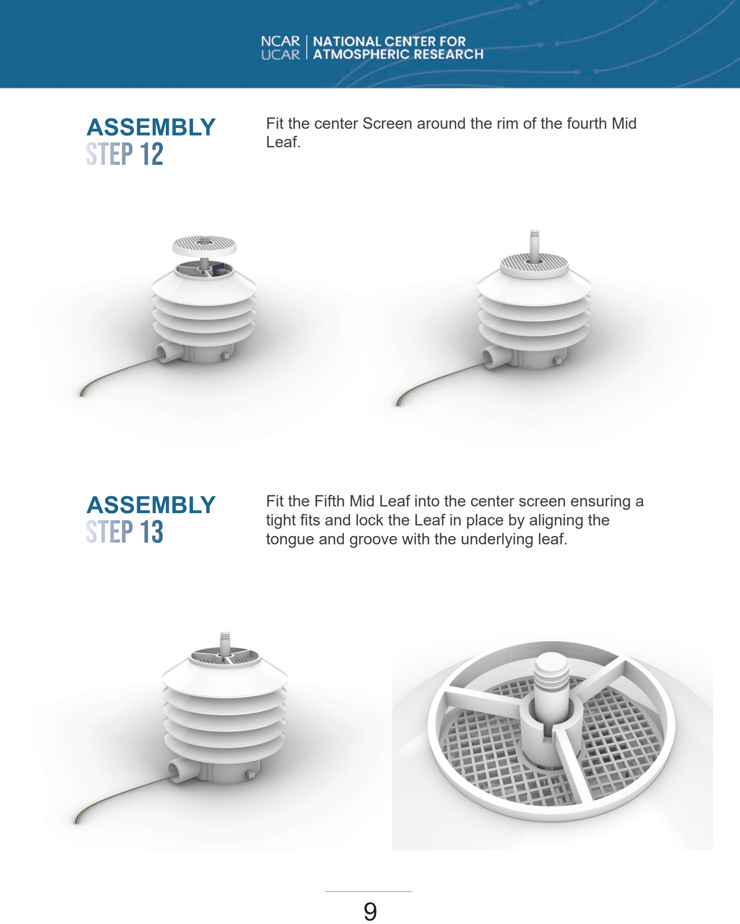
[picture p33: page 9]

ASSEMBLY | F it t he F if t h M id L eaf int o t he cent er screen ensuring a
t ig ht f it s and lock t he L eaf in p lace by alig ning t he STEP 13 | t ong ue and g roov e wit h t he underlying leaf .
ASSEMBLY | F it t he cent er S creen around t he rim of t he f ourt h M id

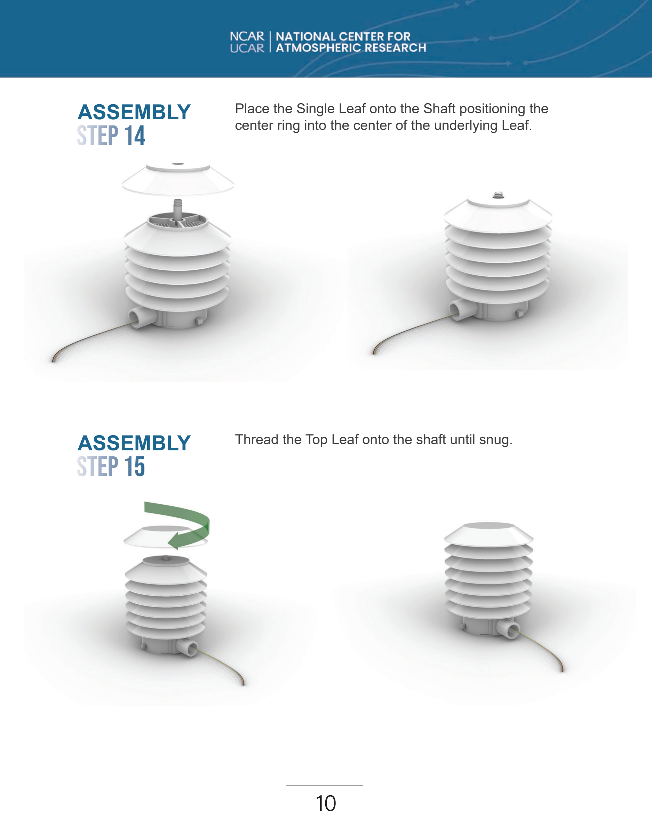
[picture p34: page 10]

ASSEMBLY Thread t he Top L eaf ont o t he shaf t unt il snug .

## STEP 15

ASSEMBLY P lace t he S ing le L eaf ont o t he S haf t p osit ioning t he cent er ring int o t he cent er of t he underlying L eaf . STEP 14

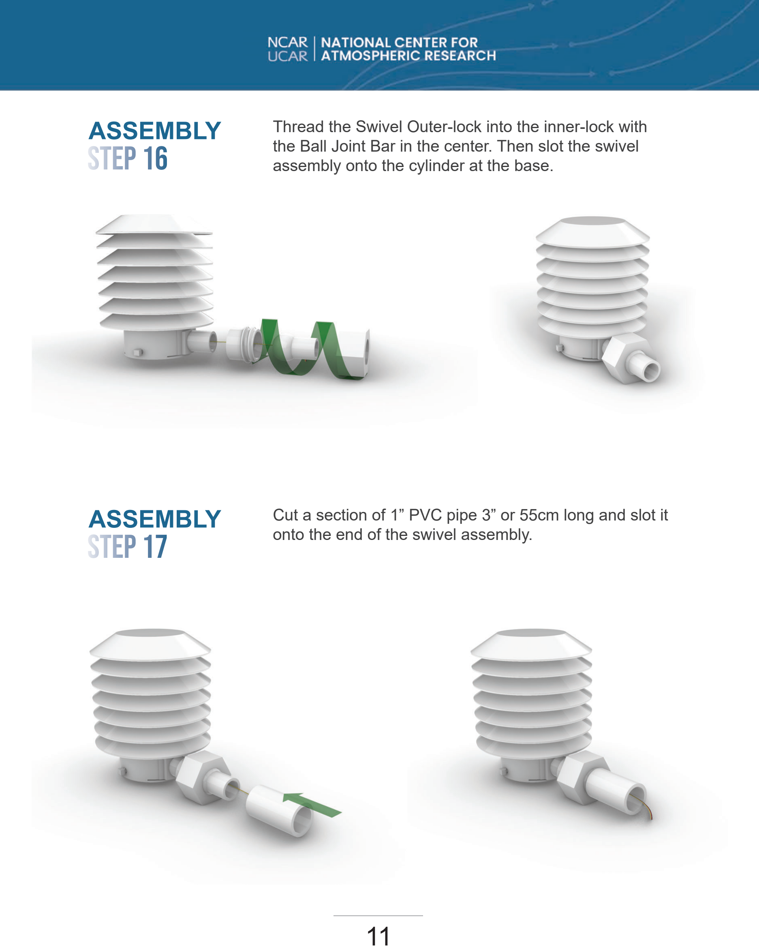
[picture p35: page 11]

ASSEMBLY C ut a sect ion of 1” P V C p ip e 3 ” or 55cm long and slot it ont o t he end of t he swiv el assembly. STEP 17

ASSEMBLY | Thread t he S wiv el O ut er- lock int o t he inner- lock wit h
t he B all J oint B ar in t he cent er. Then slot t he swiv el STEP 16 | assembly ont o t he cylinder at t he base.

## ASSEMBLY

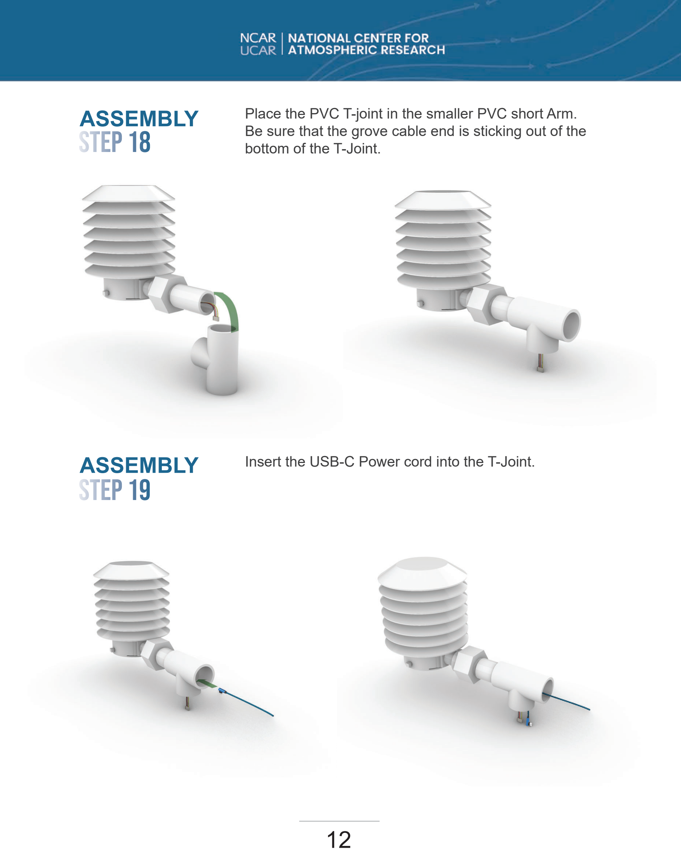
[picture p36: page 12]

## ASSEMBLY

I nsert t he U S B - C P ower cord int o t he T- J oint .

## STEP 19

P lace t he P V C T- j oint in t he smaller P V C short A rm.
B e sure t hat t he g rov e cable end is st ick ing out of t he STEP 18 | bot t om of t he T- J oint .

## ASSEMBLY

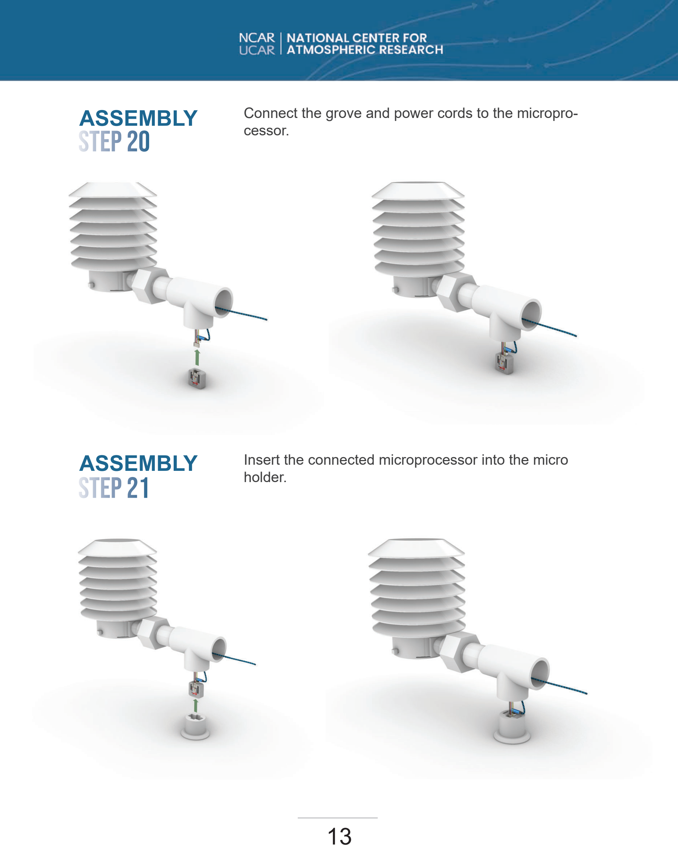
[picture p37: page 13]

## ASSEMBLY

I nsert t he connect ed microp rocessor int o t he micro holder. STEP 21

C onnect t he g rov e and p ower cords t o t he microp rocessor. STEP 20

## ASSEMBLY

## STEP 22

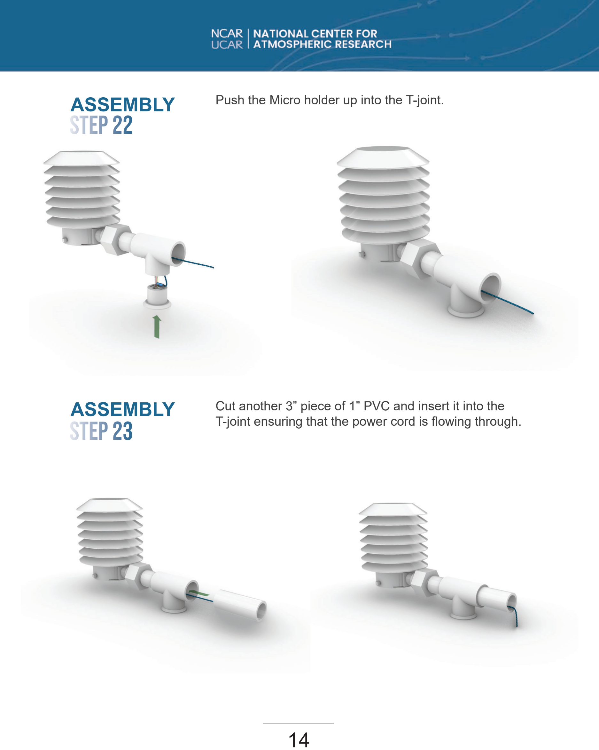
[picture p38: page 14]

## ASSEMBLY

C ut anot her 3 ” p iece of 1” P V C and insert it int o t he T- j oint ensuring t hat t he p ower cord is f lowing t hroug h. STEP 23

P ush t he M icro holder up int o t he T- j oint .

ASSEMBLY The wires and assembly should be assembled as such.

## COMPLETE

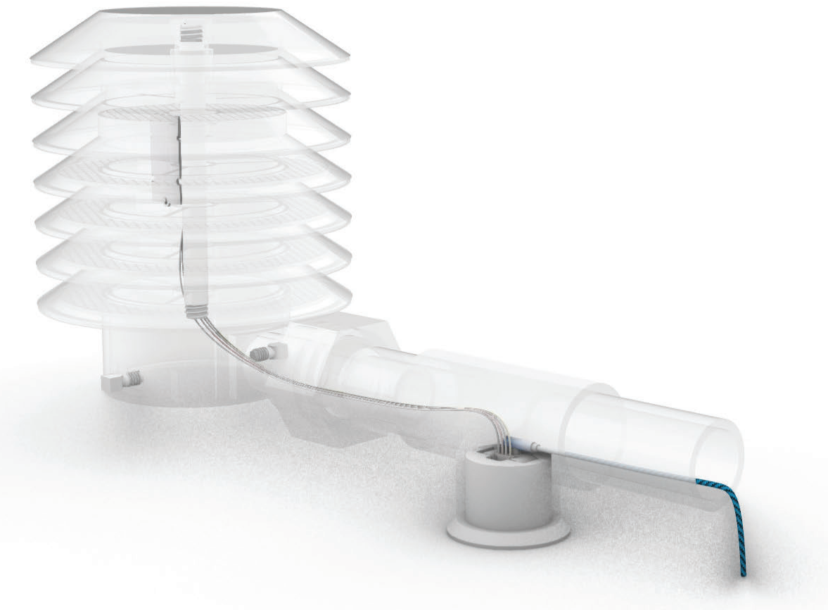
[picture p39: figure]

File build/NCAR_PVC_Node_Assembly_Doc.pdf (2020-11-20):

I O T W X P V C N O D E ASSEMBLY

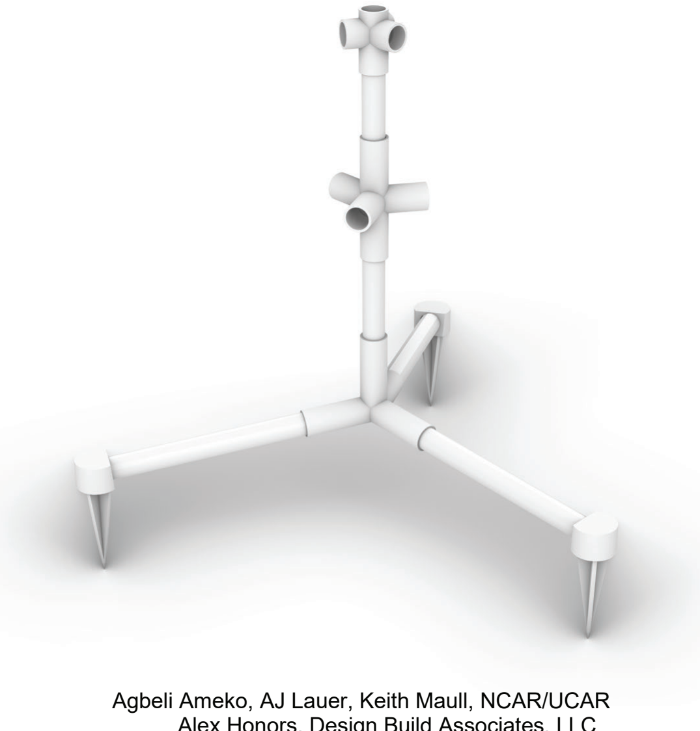
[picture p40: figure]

A g beli A m ek o, A J L auer, K eith Maull, N CA R / U CA R A lex H onors, D esig n B uild A ssociates, L L C

MIT O pensource L icense

T his m aterial is based upon w ork supported by the N ational Center for A tm ospheric R esearch, a m aj or facility sponsored by the N ational Science F oundation and m anag ed by the U niv ersity Corporation for A tm ospheric R esearch. A ny opinions, finding s and conclusions or recom m endations expressed in this m aterial do not necessarily reflect the v iew s of the N ational Science F oundation.

T his w ork is based on support prov ided by the E SIP L ab w ith support from the N ational
A eronautics and Space A dm inistration ( N A SA ) , N ational O ceanic and A tm ospheric A dm inistration ( N O A A ) and the U nited States G eolog ic Surv ey ( U SG S).

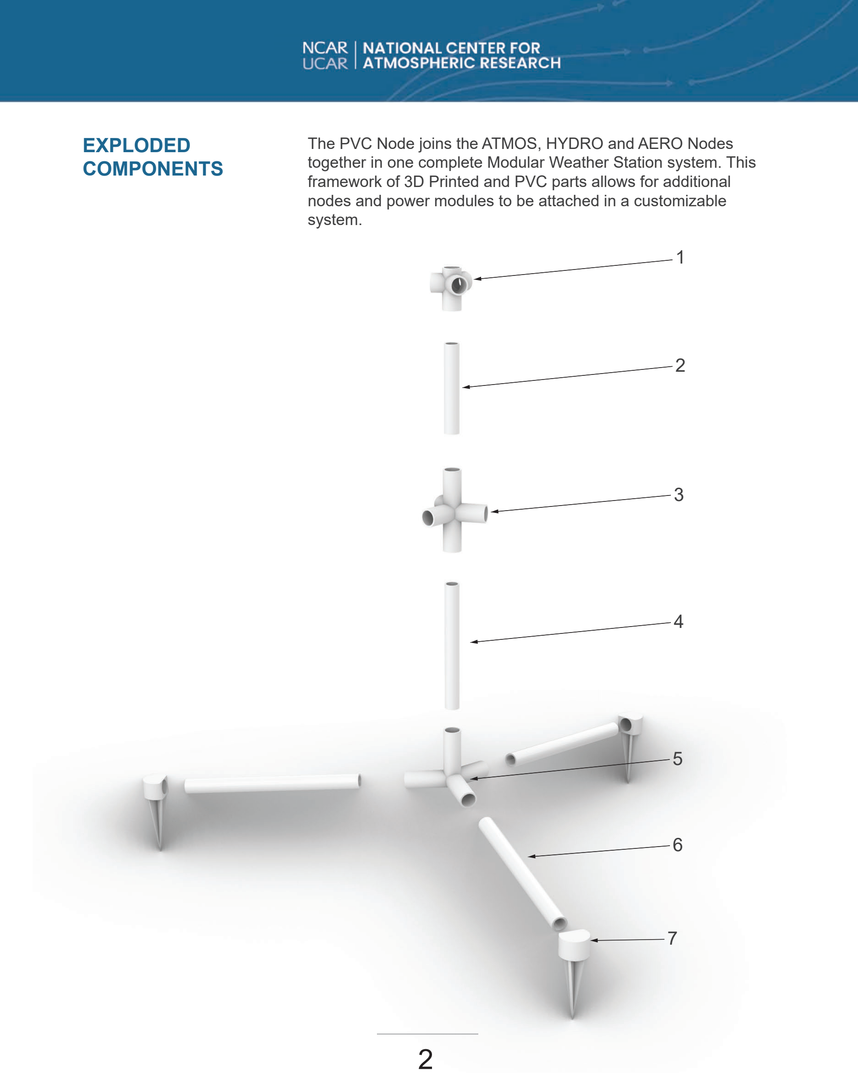
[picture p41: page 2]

EX P LO D ED
C O MP O N EN T S

T he PVC N ode j oins the A T MO S, H Y D R O and A E R O N odes tog ether in one com plete Modular W eather Station sy stem . T his fram ew ork of 3 D Printed and PVC parts allow s for additional nodes and pow er m odules to be attached in a custom iz able
sy stem .
1

2

4

5

6

7

3

C O MP O N EN T S
LI ST

ASSEMBLY

N o . | C o m p o n e n t N a m e | Q u a l i t y
1 | 3 D Printed PVC T ri- Splitter | 1
2 | T op Shaft 1” PVC | 1
3 | 3 D Printed PVC Mid Splitter | 1
4 | B ottom Shaft 1” PVC | 1
5 | 3 D Printed PVC B ase Splitter | 1
6 | B ase L eg s 1” PVC | 3
7 | 3 D Printed PVC Stak e | 3

Cut a 16” long piece of 1” PVC. A pply a lay er of PVC g lue to the slot in the PVC Stak e. Insert the PVC pipe into the Stak e.

# ST EP 1

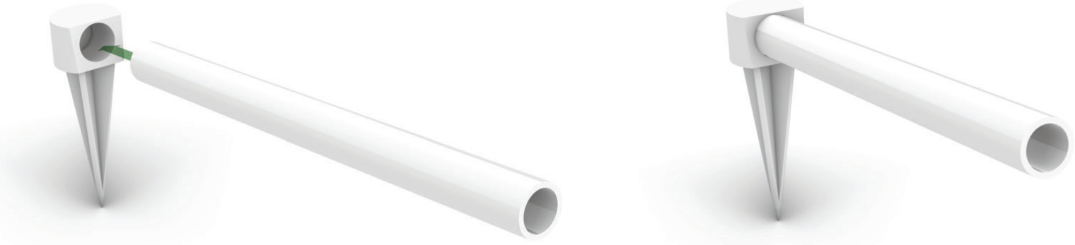
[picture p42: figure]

# ST EP 2

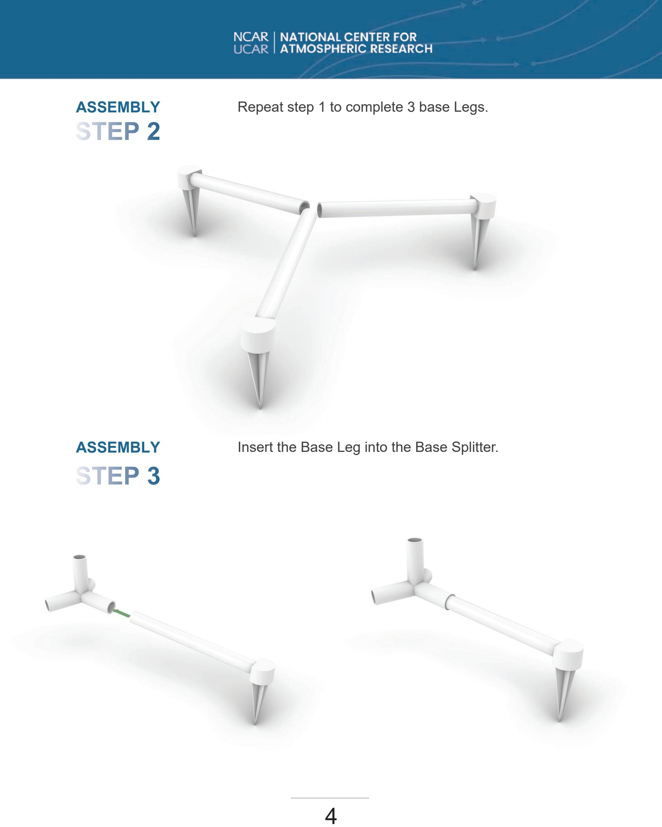
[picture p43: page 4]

ASSEMBLY | Insert the B ase L eg into the B ase Splitter.

# ST EP 3

ASSEMBLY | R epeat step 1 to com plete 3 base L eg s.

# ST EP 4

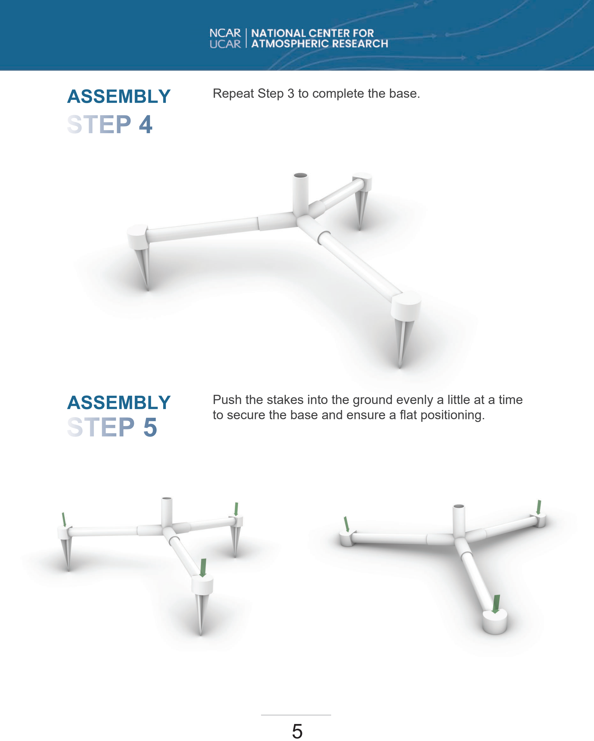
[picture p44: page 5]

ASSEMBLY Push the stak es into the g round ev enly a little at a tim e to secure the base and ensure a flat positioning . ST EP 5

ASSEMBLY R epeat Step 3 to com plete the base.

## STEP 6

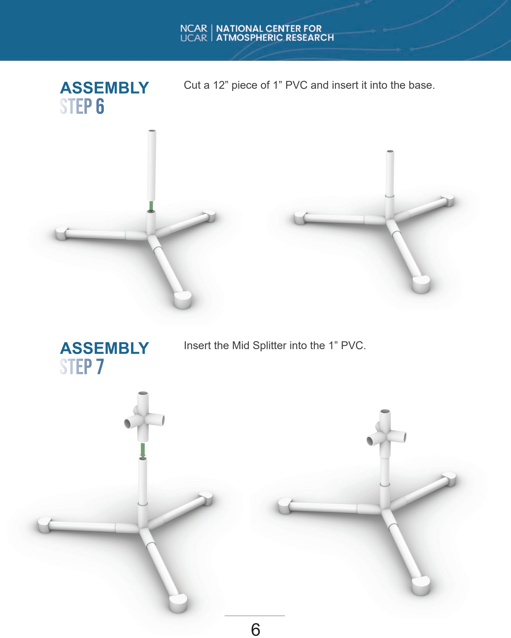
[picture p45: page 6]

ASSEMBLY Insert the Mid Splitter into the 1” PVC.

## STEP 7

ASSEMBLY Cut a 12” piece of 1” PVC and insert it into the base.

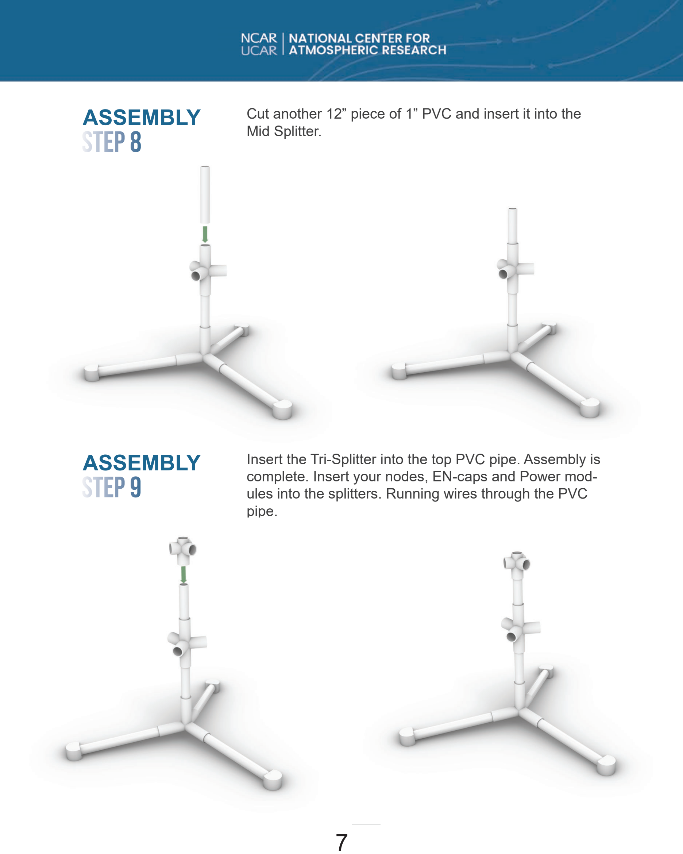
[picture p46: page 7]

ASSEMBLY Insert the T ri- Splitter into the top PVC pipe. A ssem bly is com plete. Insert y our nodes, E N - caps and Pow er m od- ules into the splitters. R unning w ires throug h the PVC pipe.

## STEP 9

ASSEMBLY Cut another 12” piece of 1” PVC and insert it into the Mid Splitter. STEP 8

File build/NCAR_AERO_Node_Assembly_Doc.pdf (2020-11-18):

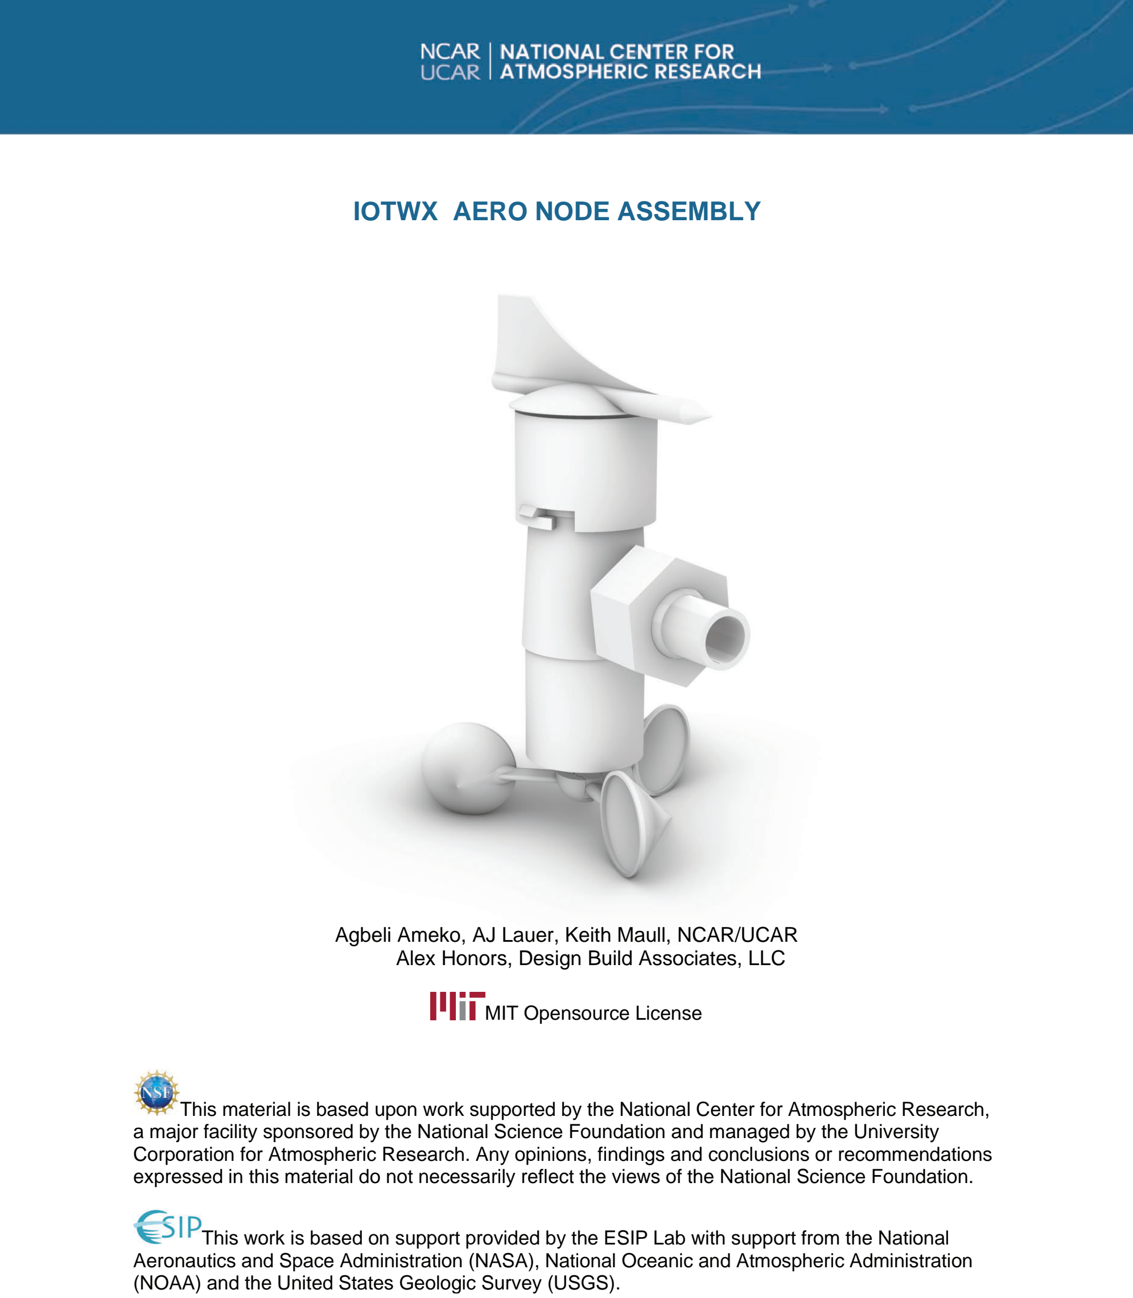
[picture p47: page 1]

IOTWX AERO NODE ASSEMBLY

Agbeli Ameko, AJ Lauer, Keith Maull, NCAR/UCAR Alex Honors, Design Build Associates, LLC

MIT Opensource License

This material is based upon work supported by the National Center for Atmospheric Research, a major facility sponsored by the National Science Foundation and managed by the University Corporation for Atmospheric Research. Any opinions, findings and conclusions or recommendations expressed in this material do not necessarily reflect the views of the National Science Foundation.

This work is based on support provided by the ESIP Lab with support from the National Aeronautics and Space Administration (NASA), National Oceanic and Atmospheric Administration (NOAA) and the United States Geologic Survey (USGS).

## EXPLODED COMPONENTS

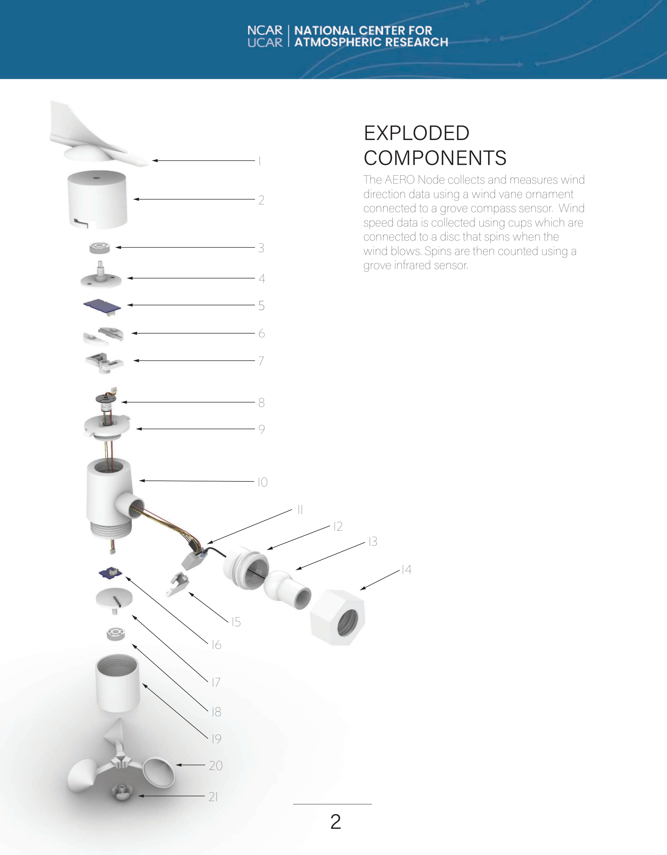
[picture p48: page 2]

The AERO Node collects and measures wind direction data using a wind vane ornament connected to a grove compass sensor. Wind speed data is collected using cups which are connected to a disc that spins when the wind blows. Spins are then counted using a grove infrared sensor.

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
## COMPONENTS LIST

## ASSEMBLY

# | DESCRITION | QUANTITY

1 | Ornament | 1
2 | Wind Vane Hull | 1
3 | Wind Vane Bearing | 1
4 | Wind Vane Plate | 1
5 | Grove Compass Sensor | 1
6 | Wind Vane Plate Clips | 1
7 | Wind Vane Coupler | 1
8 | Comidox Slip Ring Capsole | 1
9 | Wind Vane Cap | 1
10 | Center Hull | 1
11 | Microprocessor | 1
12 | Swivel Innerlock | 1
13 | Swivel Ball Joint Bar | 1
14 | Swivel Outerlock | 1
15 | Micro Harness | 1
16 | Wind Speed Plate | 1
17 | Grove Infrared Sensor | 1
18 | Wind Speed Bearing | 1
19 | Wind Speed Hull | 1
20 | Wind Speed Cups | 1
21 | Wind Speed Cup Connector | 1

# STEP 1

Align the slots on the cap connector with the groves on the cups and connect them one at a time.

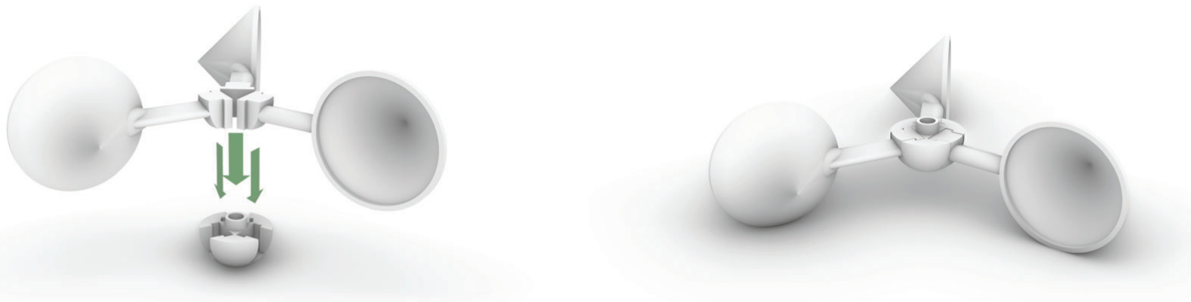
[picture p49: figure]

## ASSEMBLY

# STEP 2

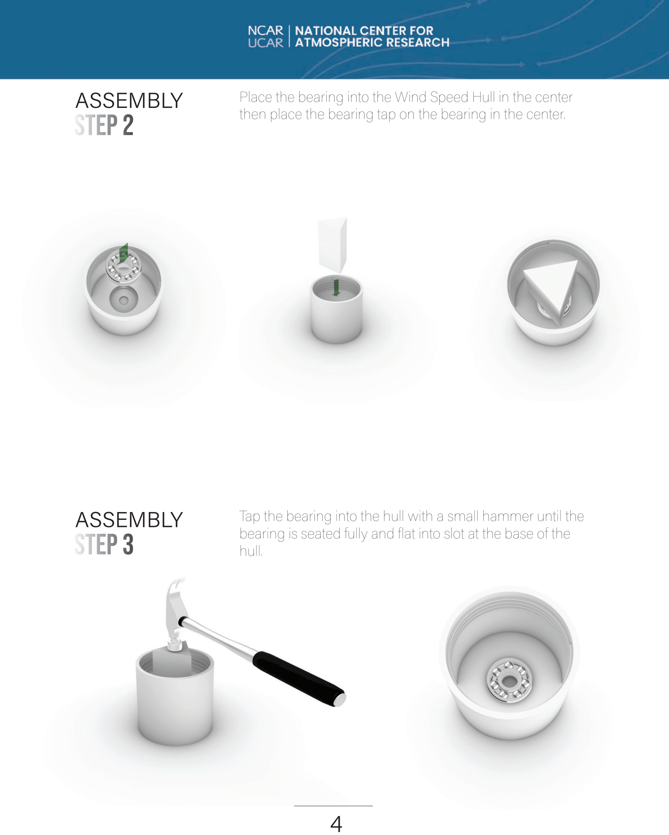
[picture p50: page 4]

## ASSEMBLY

# STEP 3

Tap the bearing into the hull with a small hammer until the bearing is seated fully and flat into slot at the base of the hull.

Place the bearing into the Wind Speed Hull in the center then place the bearing tap on the bearing in the center.

## ASSEMBLY

# STEP 4

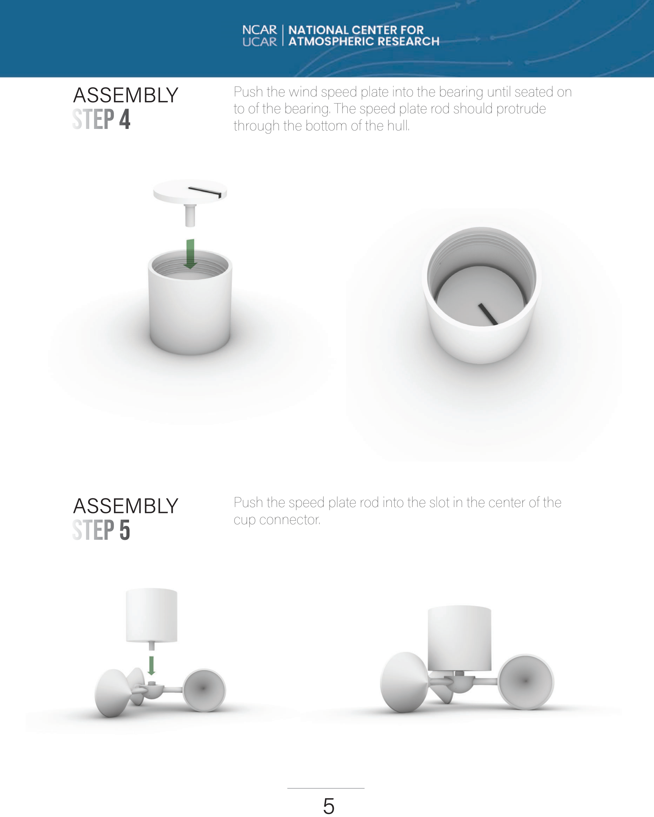
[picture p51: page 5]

## ASSEMBLY

# STEP 5

Push the speed plate rod into the slot in the center of the cup connector.

Push the wind speed plate into the bearing until seated on to of the bearing. The speed plate rod should protrude through the bottom of the hull.

## ASSEMBLY

# STEP 6

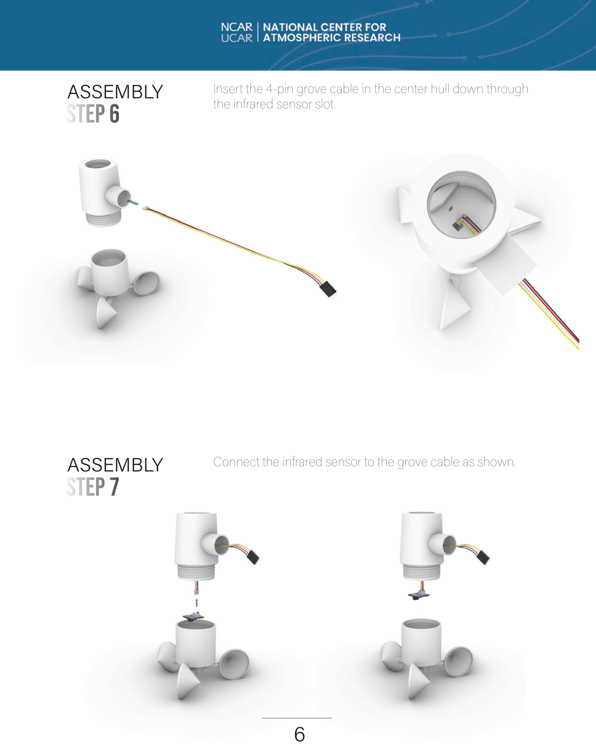
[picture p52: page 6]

## ASSEMBLY

# STEP 7

Connect the infrared sensor to the grove cable as shown.

Insert the 4-pin grove cable in the center hull down through the infrared sensor slot.

## ASSEMBLY

# STEP 8

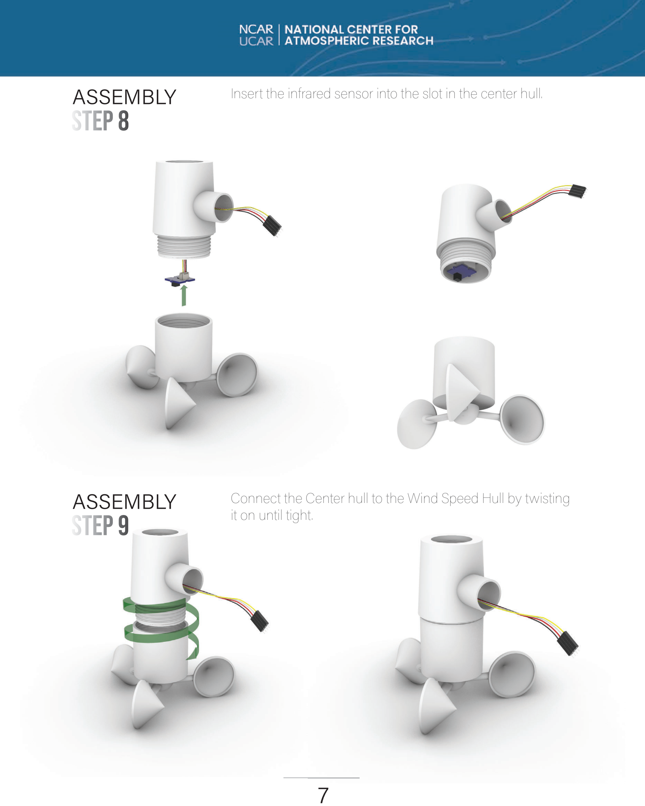
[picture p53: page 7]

## ASSEMBLY

Connect the Center hull to the Wind Speed Hull by twisting it on until tight.

Insert the infrared sensor into the slot in the center hull.

## ASSEMBLY

# STEP 10

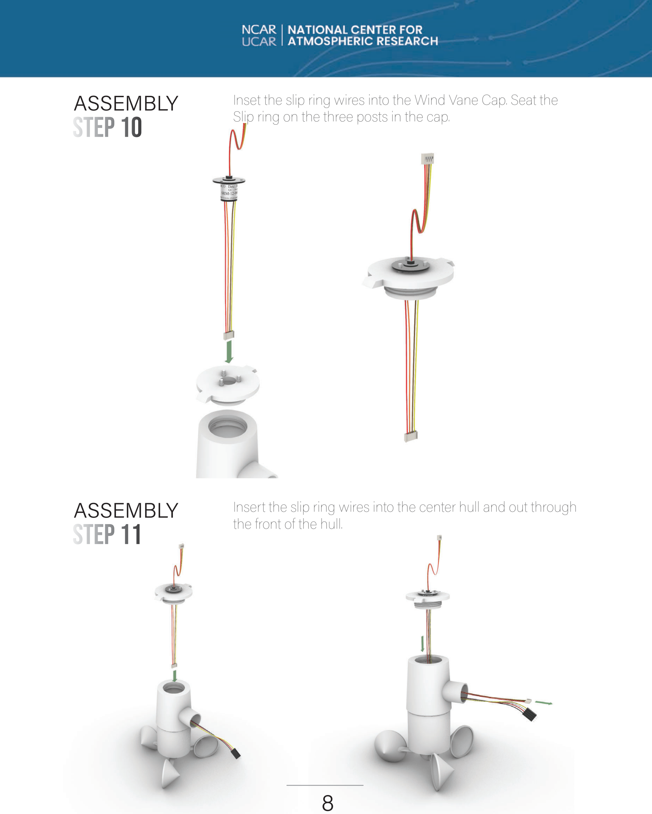
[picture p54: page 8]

## ASSEMBLY

# STEP 11

Insert the slip ring wires into the center hull and out through the front of the hull.

Inset the slip ring wires into the Wind Vane Cap. Seat the Slip ring on the three posts in the cap.

## ASSEMBLY

# STEP 12

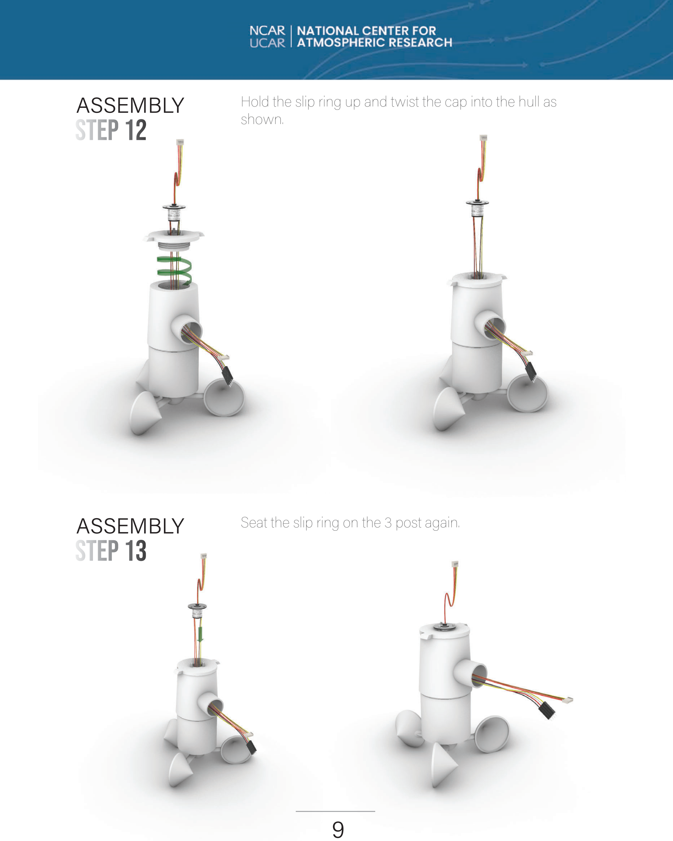
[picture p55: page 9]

## ASSEMBLY

# STEP 13

Seat the slip ring on the 3 post again.

Hold the slip ring up and twist the cap into the hull as shown.

## ASSEMBLY

# STEP 14

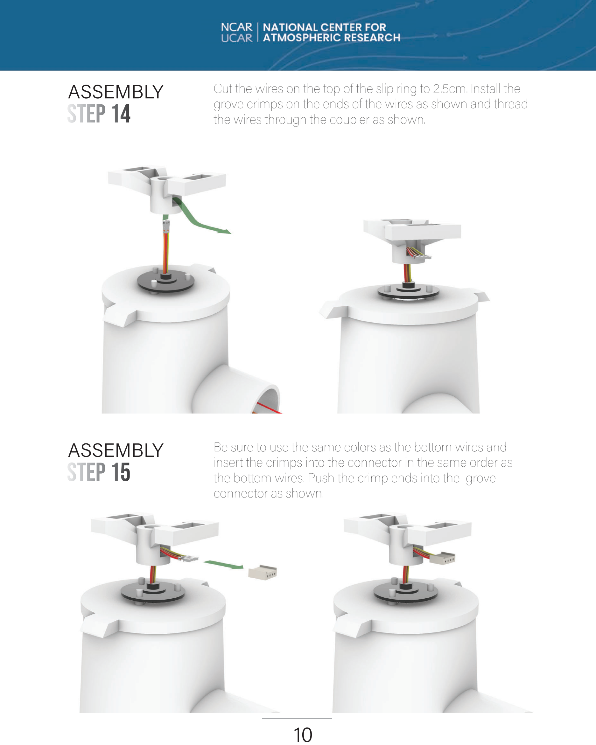
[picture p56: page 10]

## ASSEMBLY

# STEP 15

Be sure to use the same colors as the bottom wires and insert the crimps into the connector in the same order as the bottom wires. Push the crimp ends into the grove connector as shown.

Cut the wires on the top of the slip ring to 2.5cm. Install the grove crimps on the ends of the wires as shown and thread the wires through the coupler as shown.

## ASSEMBLY

# STEP 16

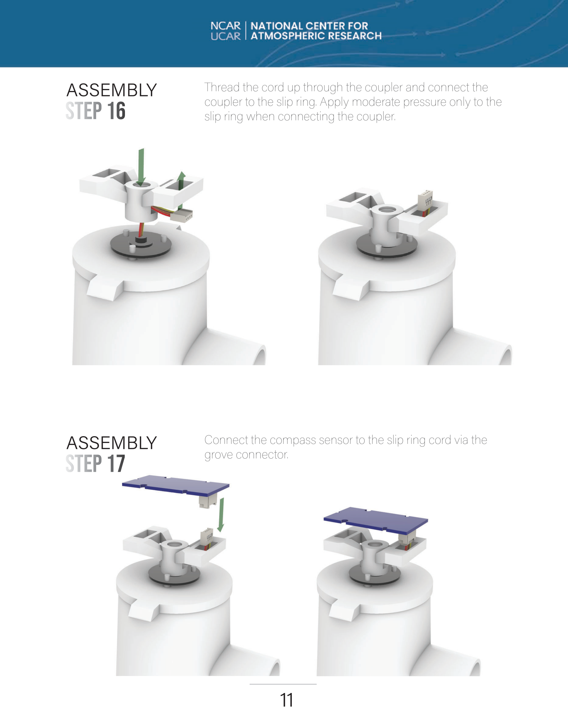
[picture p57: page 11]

## ASSEMBLY

# STEP 17

Connect the compass sensor to the slip ring cord via the grove connector.

Thread the cord up through the coupler and connect the coupler to the slip ring. Apply moderate pressure only to the slip ring when connecting the coupler.

## ASSEMBLY

# STEP 18

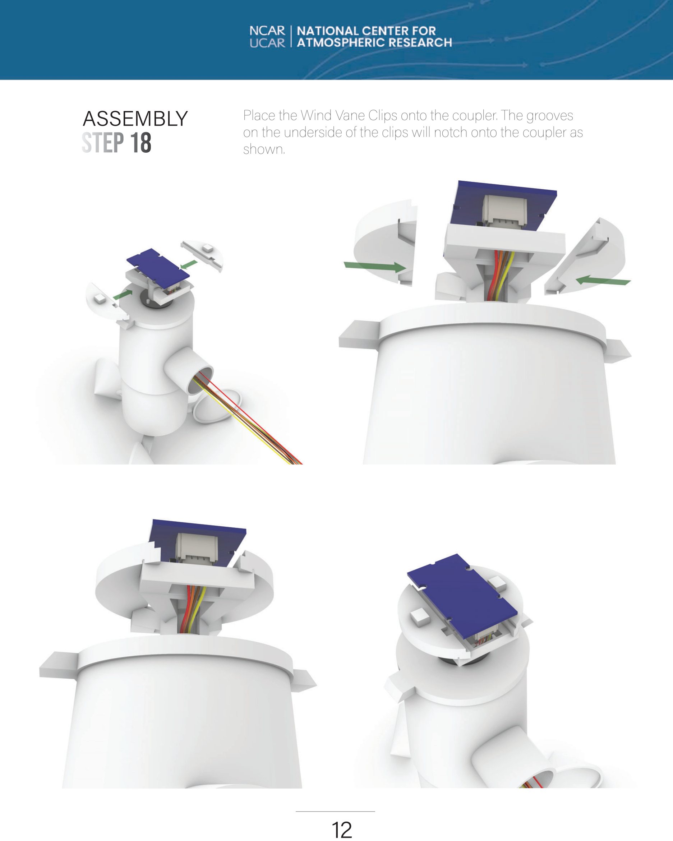
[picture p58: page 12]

Place the Wind Vane Clips onto the coupler. The grooves on the underside of the clips will notch onto the coupler as shown.

## ASSEMBLY

# STEP 19

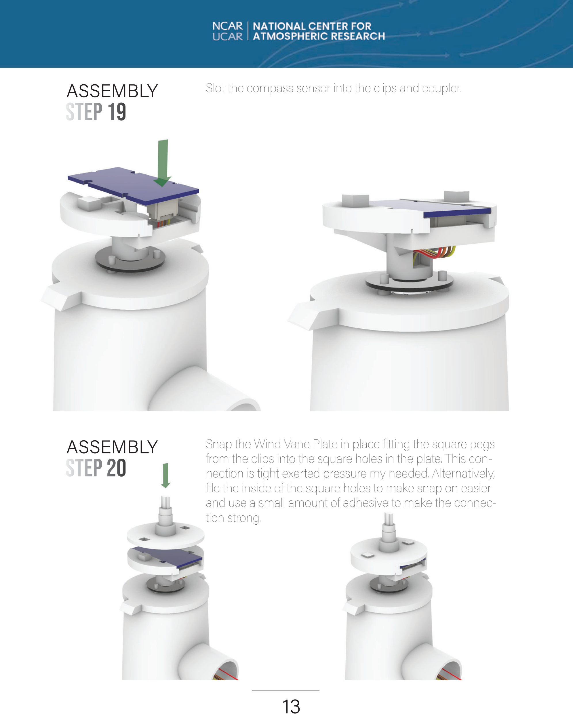
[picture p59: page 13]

## ASSEMBLY

# STEP 20

Snap the Wind Vane Plate in place fitting the square pegs from the clips into the square holes in the plate. This connection is tight exerted pressure my needed. Alternatively, file the inside of the square holes to make snap on easier and use a small amount of adhesive to make the connection strong.

Slot the compass sensor into the clips and coupler.

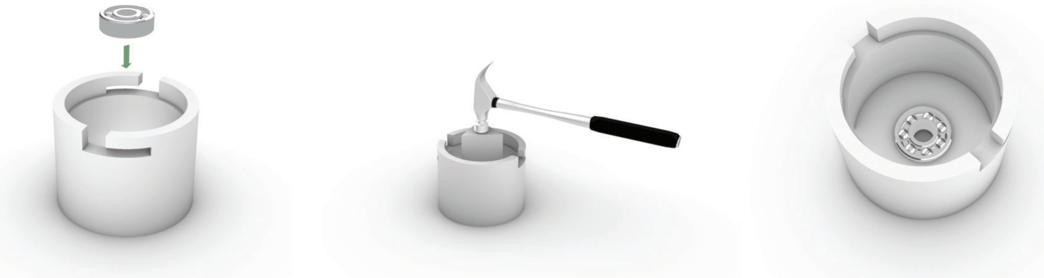
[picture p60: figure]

## ASSEMBLY

# STEP 22

Insert the hull into the cap applying moderate pressure to slip the wind vane plate through the bearing and out of the top of the hull. This connection is a tight fit exerted eort may be needed to secure this connection. Alternatively remove the Wind Speed Cups at the bottom of the assembly in order to have a solid foundation to push the wind speed plate through the bearing. This will require removing the Wind Speed Hull in order to reconnect the cups.

## ASSEMBLY

# STEP 21

Use the Bearing tapper to slot the bearing into the Wind Vane Hull.

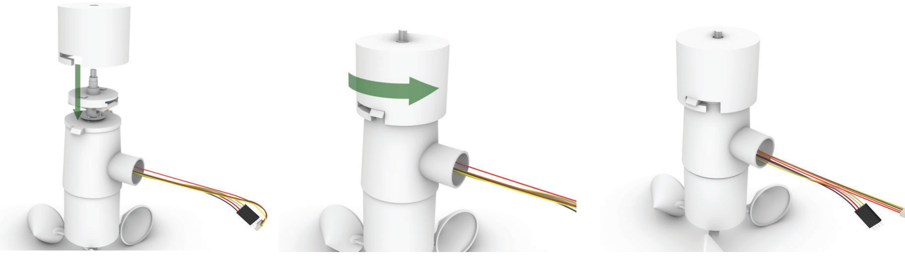
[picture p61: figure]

## ASSEMBLY

# STEP 23

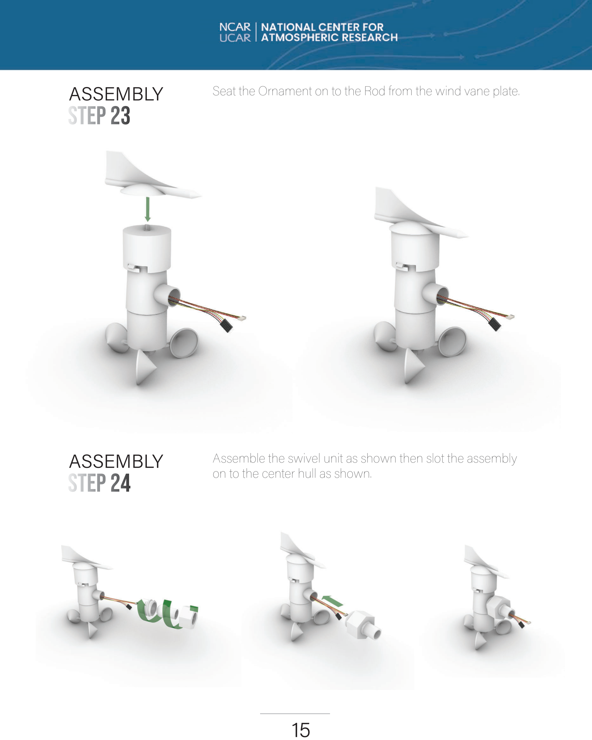
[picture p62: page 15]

## ASSEMBLY

# STEP 24

Assemble the swivel unit as shown then slot the assembly on to the center hull as shown.

Seat the Ornament on to the Rod from the wind vane plate.

## ASSEMBLY

# STEP 25

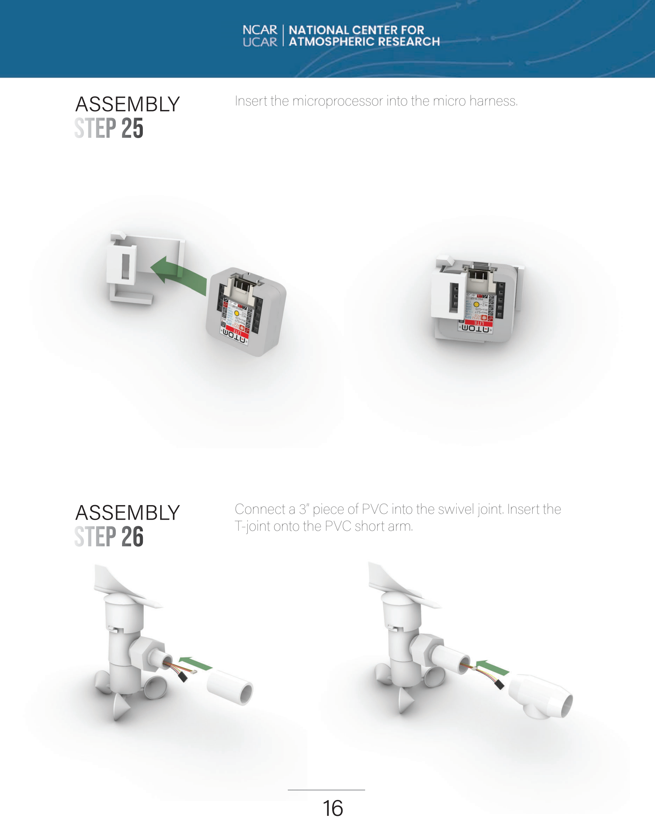
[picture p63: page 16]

## ASSEMBLY

# STEP 26

Connect a 3” piece of PVC into the swivel joint. Insert the T-joint onto the PVC short arm.

Insert the microprocessor into the micro harness.

## ASSEMBLY

# STEP 27


## ASSEMBLY

# STEP 28

Insert the Power Cord though the T-Joint and connect it to the microprocessor a th USB-C hub.

Connect the 4-Pin grove wires through the harness. Connect the crimp grove slip ring wires to the grove slot in the micro processor.

## ASSEMBLY

# STEP 29


## ASSEMBLY

# STEP 30

Insert the micro holder into the T-Joint. Insert the final 3” PVC.

Place the microprocessor into the micro holder.

## ASSEMBLY

# COMPLETE

The AERO Node Should be assembled as shown.


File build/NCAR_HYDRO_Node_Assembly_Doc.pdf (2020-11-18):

I O T W X H YD R O N O D E ASSEMBLY; MI T O pensource L icense

A g beli A mek o, A J L auer, K eith Maull, N CA R / U CA R A lex Honors, D esig n B uild A ssociates, L L C

This material is based upon w ork supported by the N ational Center f or A tmospheric R esearch, a maj or f acility sponsored by the N ational Science F oundation and manag ed by the U niv ersity Corporation f or A tmospheric R esearch. A ny opinions, f inding s and conclusions or recommendations expressed in this material do not necessarily ref lect the v iew s of the N ational Science F oundation.

This w ork is based on support prov ided by the E SI P L ab w ith support f rom the N ational
A eronautics and Space A dministration ( N A SA ) , N ational O ceanic and A tmospheric A dministration ( N O A A ) and the U nited States G eolog ic Surv ey ( U SG S).

## EX P LO D ED C O MP O N EN T S


The HY D R O N ode collects and measures precipitation using a
1 millimeter rain g aug e and f ree standing f unnel. The rain g aug e is retro f itted w ith mag nets using a customize d arm ext ending f rom the g aug e to a g rove hall ef f ect sensor situated w ithin the f unnel.

1

2

3

7 | 8

6

9

5

4

C O MP O N EN T S | N o . | C o m p o n e n t N a m e | Q u a l i t y

## LI ST

## ASSEMBLY

1 | F unnel Screen | 1
2 | F unnel | 1
3 | Hydro Slot | 1
4 | Hydro G aug e | 1
5 | F ulcrum | 1
6 | Hydro B ase | 1
7 | Sw ive l I nnerlock | 1
8 | Sw ive l B all Joint B ar | 1
9 | Sw ive l O uterlock | 1

## STEP 1

A lig n the holes in the Hydro G aug e w ith holes in the center of the Hydro B ase and insert the F ulcrum into the hole in the center of the G aug e. Secure the f ulcrum by snapping the pins in on both sides. I nsert the small mag net into the circular slot on the arm of the Hydro

G aug e.

## ASSEMBLY

## STEP 2


## ASSEMBLY

## STEP 3

A lig n the holes on the side of G rove Hall E f f ect Senor w ith the tw o circular ext rusions on the Hydro Slot and seat the sensor in the sensor slot as show n

A lig n the leg s on the Hydro Slot w ith linear g roove s in the w alls of the Hydro B ase and insert the Slot into the base.

## ASSEMBLY

## STEP 4


## ASSEMBLY

## STEP 5

A f ter threading the w ire throug h connect the w ire to the hall ef f ect sensor.

Thread the g rove w ire dow n throug h the cylindrical hole in the Hydro B ase and out throug h the f ront to the cylinder in the base.

## ASSEMBLY

## STEP 6


## ASSEMBLY

## STEP 7

A lig n the leg s of the F unnel Screen w ith the g roove s in the F unnel and place the F unnel Screen on top of the f unnel

Slip the F unnel ove r the B ase seating the f unnel on the rim of the base.

## ASSEMBLY

## STEP 8


## ASSEMBLY

## STEP 9

Cut a 3 inch piece of 1” diameter PV C and slot it on to the end of the Sw ive l Joint assembly ensuring that the g rove w ire is f low ing throug h the PV C.

A lig n the Sw ive l I nnerlock, B all-j oint B ar, and O uterlock respective ly and assemble by tw isting the outerlock onto the innerlock until tig ht w ith the ball-j oint bar in betw een. Then push the sw ive l assembly on the cylinder of the base allow ing the g rove w ire to pass throug h the assembly..

## ASSEMBLY

## STEP 10


## ASSEMBLY

## STEP 11

I nsert the U SB -C pow er Cord onto the PV C T-Joint ensuring that the cord is coming out throug h the bottom of the T-Joint.

Place your PV C T-Joint onto the smaller PV C ensuring that the g rove w ire f low s out of the bottom of the T-Joint.

## ASSEMBLY

## STEP 12


## ASSEMBLY

## STEP 13

Connect the Micro controller to the G rove Cord and the Pow er Cord

Cut a second 3 ” piece of 1” PV C and attach it to the T-Joint ensuring that the pow er cord is f low ing throug h the end of the PV C.

## ASSEMBLY

## STEP 14


## ASSEMBLY

## STEP 15

Push the Micro Holder into the T-Joint and assembly is complete.

Slot the Connected Microcontoller into the Micro Holder.

## ASSEMBLY

## COMPLETE

The G rove Cords and Pow er Cords Should run throug h the A ssembles Hydro Module as show n.


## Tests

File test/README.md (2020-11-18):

--
## Set up MQTT Broker 
### What is MQTT?

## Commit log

2021-01-25 added assembly doc
2021-01-25 updated stl file base
    [aero_wnvn_cap_2.stl, pvc_mid_splitter.stl, pvc_tri_splitter_2.stl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]
2021-03-07 updated skeleton and wiring; added data section
2021-03-08 added micro harness for 4 pin jumper adapter for using ir sensor and compass simultaneously
    [aero_micro_harness.stl]
2021-03-08 added missing brackets
2021-03-09 updated harness for adafruit qwiic sensor
    [aero_wnvn_coupler_4.stl, aero_wnvn_plate_4.stl]
2021-03-09 aligned base with plane in stl
    [rs_screen_ring.stl]
